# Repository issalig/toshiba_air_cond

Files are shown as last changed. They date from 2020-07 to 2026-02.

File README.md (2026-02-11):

# toshiba_air_cond
This project implements functions to decode Toshiba AB protocol from indoor units to wired controllers and provides a hardware design for communication.

Gerbers are available but remember if you improve the design please share it, that's how open source works, if you do not want to share, this project is not for you.

I strongly recommend to use [makusets' board](https://github.com/makusets/esphome-toshiba-ab/tree/main/hardware/D1%20mini) instead of my custom hardware.
My hardware is designed assuming a voltage level of the AB line around 15.6V when "1" and 14V when "0". Different voltage values will not work for writing while reading will work.

In particular, this project has been tested with remote control unit RBC-AMT32E and central unit RAV-SM406BTP-E (http://www.toshiba-aircon.co.uk/assets/uploads/product_assets/20131115_IM_1115460101_Standard_Duct_RAV-SM_6BTP-E_EN.pdf)

You can find the service manual from central unit and wired controller here: http://www.toshibaclim.com/Portals/0/Documentation/Manuels%20produits/SM_Gainable_Std-Compact--DI_406566806110614061606_GB.pdf, https://rednux.com/mediafiles/Hersteller/toshiba/Toshiba-Bedienungsanleitung-RBC-AMT32E-Englisch.pdf

## Index

[Software installation](#Software-installation)

[Web Interface](#Web-Interface)

[Home Assistant & MQTT](#Home-Assistant-&-MQTT)

[Hardware Installation](#Hardware-Installation)

[Custom hardware](#Custom-hardware)

[Data format](#Data-format)

[Message types](#Message-types)

[Other info](#Other-info)
 
# Software installation
[Up](#toshiba_air_cond) [Previous](#Index) [Next](#Hardware-Installation)

Code is developed in PlatformIO for ESP8266 and in particular for Wemos D1 mini board. It is basically a WebServer that serves a webpage and communicates with the client by means of WebSockets. It also offers Home Assistant integration and has nice features usch as OTA updates, file uploading, WifiManager and others.

### Dependencies

This project uses libraries and code from different authors, they are installed automatically from platformio.ini file

- [esp8266](https://github.com/esp8266/Arduino)
- [espsoftwareserial](https://github.com/plerup/espsoftwareserial) by Peter Lerup
- [WiFiManager](https://github.com/tzapu/WiFiManager) by tzapu
- [WebSockets](https://github.com/Links2004/arduinoWebSockets) by Links2004
- [ArduinoJson](https://github.com/bblanchon/ArduinoJson) by Benoit Blanchon
- [Adafruit libraries](https://github.com/adafruit) Adafruit SSD1306, Adafruit GFX Library, adafruit/Adafruit AHTX0 and adafruit/Adafruit BMP280
- LittleFS
- [PubSubClient](https://github.com/knolleary/pubsubclient)
- NTPClient

### Compilation
First things first. Compile it with VSCode and upload it to the board with PlatformIO.

Minimal hardware is ESP8266 and the pcb for adapting signal from serial to AB line. 

- ESP8266 (Wemos D1 Mini R2)
- Toshiba AC serial interface (SoftwareSerial D7=RX, D8=TX)
- Optional I2C sensors (shared bus D1=SCL, D2=SDA):
  - AHT20 (temperature + humidity)  [enabled with `#define USE_AHT20`]
  - BMP280 (temperature + pressure) [enabled with `#define USE_BMP280`]
  - BME280 (temperature + humidity + pressure) [enabled with `#define USE_BME280`]
- Optional OLED 128x64 SSD1306 (I2C D1=SCL, D2=SDA)         [`#define USE_SCREEN`]
- Reset / Config button on D4 (WiFiManager AP)
  
To sum up, the following defines are available and features are disabled by commenting its `#define` in  [config.h](https://github.com/issalig/toshiba_air_cond/blob/master/air/config.h)

- `USE_OTA`      OTA updates
- `USE_SCREEN`   OLED status display
- `USE_MQTT`     MQTT + Home Assistant integration
- `USE_AHT20`    AHT20 sensor support
- `USE_BMP280`   BMP280 sensor support

### WiFi setup
Once you have the code uploaded it is time to configure your WiFi. This project makes use of the great WiFiManager library so there is no need to hardcode your WiFi settings.
- Plug you esp board. It will start blinking.
- Connect to **airAP** wifi network from your cellphone or PC.
- Open a browser and the WifiManager will appear.
- Select your WiFi network and the password.
- If everything is correct, airAP shuts down and board connects to your WiFi.
- Connect to your normal WiFi from computer/cellphone.

### Connect
Now the esp8266 is connected to your network and can be reached as http://air.local

### Upload files
Connect to http://air.local/filemanager, type index.html and upload it.

This will store index.html file and http://air.local should show the main page.
You can use this endpoint to modify the webpage or add more functionality. If you do it please share.

### Delete files
Similarly to upload page you can use http://air.local/filemanager to delete a file.

### OTA and file update
OTA updates are available, so you do not need to unplug the esp everytime you want to flash it. In the Arduino IDE just set Tools->Port->air at xxx.
If you are using PlatformIO it is done in platform.io
Default OTA password is esp8266

```
; OTA upload configuration
upload_protocol = espota
upload_port = air.local        ; Replace with your device's actual IP from OTAName in config.cpp
upload_flags = --auth=esp8266  ; Replace with your OTA password from OTAPassword varialble in config.cpp
```

If you just want to upload individual files you can use http://air.local/edit.html

# Web Interface
[Up](#toshiba_air_cond) [Previous](#Software-Installation) [Next](#Hardware-Installation)

This section describes the features available through the embedded web interface served by the ESP8266 air conditioning controller.

## Access
- URL via mDNS: `http://air.local` (See `mdnsName` in `config.h`)
- HTTP Port: 80
- WebSocket Port: 81

web interface)

## Main Features
1. Control Functions
   - Power ON / OFF
   - Set target temperature (bounded 16–30 °C; internally enforced 18–30 in MQTT handler)
   - Change mode: `cool`, `heat`, `dry`, `fan_only`, `auto`, `off`
   - Change fan speed: `auto`, `low`, `medium`, `high`
   - Save mode

2. Timer
   - ON/OFF Timer. Software based relying only in esp8266

3. Chart
   - Shows current temperature, external temperature and pressure/humidity if sensors are available.

4. System
   - Info: IP, boot time and decoding errors.
   - Sensors: Internal / External AC sensors.
   - Address: Address configuration for master/remote in case your system uses different from default or you want to install different remotes.
   - Mode: 
    - Autonomous mode indicator: Use it if there is no remote connected (sends pings like remotes). It is necessary to have a temperature sensor to report room temperture.
    - Simulation mode indicator: Simulates a physical AC
   - Admin: Upload files. Use it to upload index.html and others.
5. Debug
    - Send RAW messages to AC, i.e., "00 FE 10 02 80 8A E6"
    - Debug output: Shows serial raw and decoded messages
    - Log

6. MQTT Configuration (if `USE_MQTT`)
   - Runtime modification of: host, port, username, password, device name
   - Persisted to `/mqtt_config.json` in LittleFS

# Home Assistant & MQTT
[Up](#toshiba_air_cond) [Previous](#Web-Interface) [Next](#Hardware-Installation)

If `USE_MQTT` is enabled, the device integrates with Home Assistant using MQTT Discovery.

### Discovery
The device automatically publishes configuration to:
`homeassistant/climate/toshiba_ac/config`

### Manual Configuration / Topics
If discovery is not used, here are the available topics:

| Topic Type | Topic Path | Payload / Description |
|---|---|---|
| **Status** | `homeassistant/ac/status/mode` | `cool`, `heat`, `auto`, `fan_only`, `dry`, `off` |
| **Status** | `homeassistant/ac/status/fan_mode` | `auto`, `high`, `medium`, `low` |
| **Status** | `homeassistant/ac/status/temperature` | Target Temperature (e.g. `22`) |
| **Status** | `homeassistant/ac/status/current_temperature` | Room Temperature (e.g. `21.5`) |
| **Command** | `homeassistant/ac/set/mode` | Set mode (same values as status + `on`/`off`) |
| **Command** | `homeassistant/ac/set/fan_mode` | Set fan speed |
| **Command** | `homeassistant/ac/set/temperature` | Set target temperature |

### Configuration
MQTT settings (Broker, User, Password) can be configured via the Web Interface and are saved to `/mqtt_config.json`. The device status (Power, Mode, Fan, Temperature) is periodically published and updated in real-time when changed via Web or Remote.

# Hardware installation
[Up](#toshiba_air_cond) [Previous](#Home-Assistant-&-MQTT) [Next](#Data-acquisition)

You will need an esp8266, a circuit for adapting signals to esp8266, a USB power supply, a a couple of dupont (female) wires.
- Take out the cover of your remote controller
- Loose the screws of AB terminals. **WARNING**: My PCB assumes A is positive and B is negative. If this is not your case you can damage the PCB. (https://github.com/issalig/toshiba_air_cond/discussions/40#discussioncomment-8149607)
- Pass the wires through the ventilation holes of the cover.
- Insert dupont wires on the terminals and screw them again
- Close the cover
- Connect dupont wires to the pcb (A,B)
- Plug the Wemos D1 mini into the pcb
- Power Wemos with usb cable and the led will start blinking (if you have already programmed it)

Just switch it on/off while you are in bed. If you like it just send me a beer and/or improve the project!

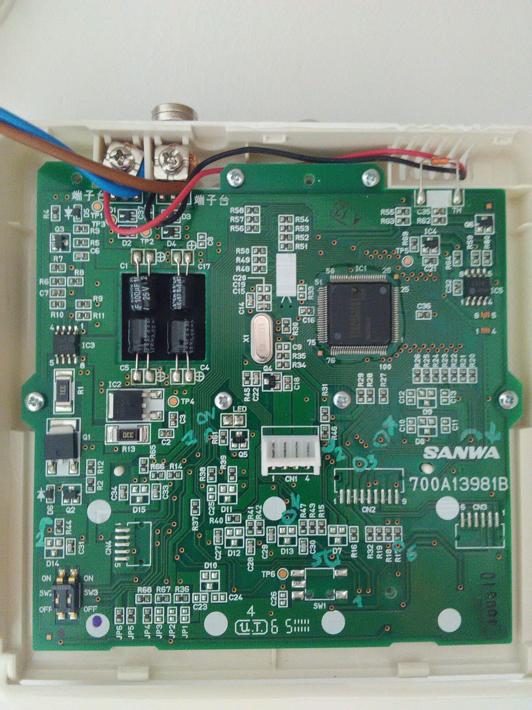
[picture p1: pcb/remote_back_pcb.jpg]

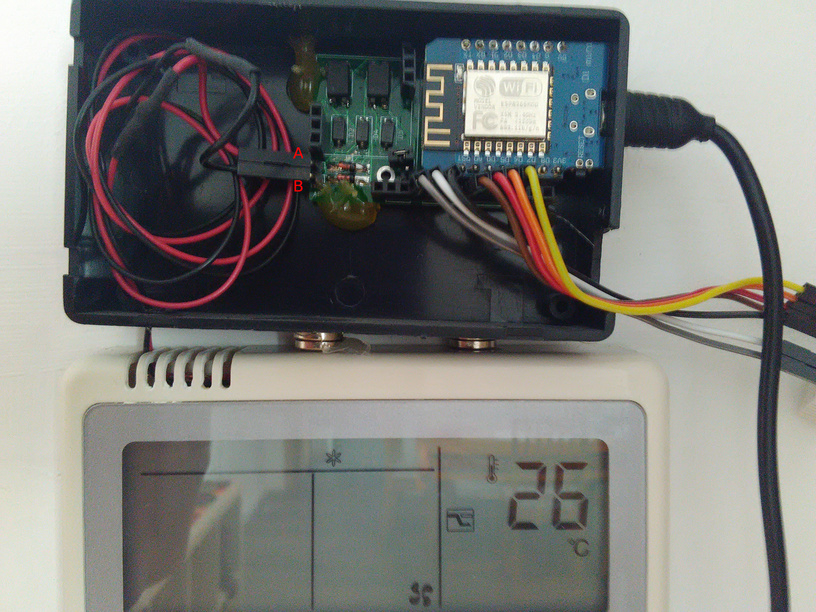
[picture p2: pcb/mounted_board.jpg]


# Data acquisition
[Up](#toshiba_air_cond) [Previous](#Hardware-Installation) [Next](#Custom-hardware)

This is how I managed to decode the information from the AB bus. First I plugged a multimeter to check the range of the signal and not fry anything. Then I used a DS0138 oscilloscope to monitor the signal and to guess voltages and baudrate (a resistor divider is suggested in order to lower the voltage). Later, an 8-channel USB logic analyzer (4-5 USD) can be used to capture data into the computer. **REMEMBER** to convert voltages to 0-3.3v before connecting it to logic analyzer or you will make magic smoke. You can use the read circuit below.

To capture data you can use pulseview with uart decoder 2400 bps, 8bits, start, stop, EVEN parity

In case you need it you can install the following packages
```
sudo apt install sigrok-cli
sudo apt install sigrok-firmware-fx2lafw
```

When the data has been validated visually you can use the following command line that reads RX data annotations and print one message per line according to 4th byte (message size).

```
sigrok-cli -P uart:rx=D0:baudrate=2400:parity_type=even -A uart=rx_data -i  YOURFILE  | awk '{pad =" "; b[len%4]=$2; if(len==3) {bytes="0x"b[len];  printf("%s%s%s%s%s%s%s%s",b[0],pad,b[1],pad,b[2],pad,b[3],pad)} if(len>3) {printf("%s%s",$2,pad);} len=len+1; if(len==4+bytes+1) {print "";len=0;bytes=0}}'
```

```
sigrok-cli -d fx2lafw -c samplerate=250000 -t D0=r -P uart:rx=D0:baudrate=2400:parity_type=even  -A uart=rx_data --continuous
```

# Custom hardware
[Up](#toshiba_air_cond) [Previous](#Data-acquisition) [Next](#Data-format)

Note: I strongly recommend to use [makusets board](https://github.com/makusets/esphome-toshiba-ab/tree/main/hardware/D1%20mini) instead of my custom hardware.
My hardware is designed assuming a voltage level of the AB line around 15.6V when "1" and 14V when "0". Different voltage values will not work for writing while reading will work.

I have designed some circuits to read and write the signal

## Read
I will use an optocoupler because it simplifies things and also isolates microcontroller from the rest of the system.

- Air conditioning side:
Voltage is around 15.6 volts when "1" and 14 when "0". A zener diode in reversed position provides 13V reference given that voltage is in the range [14, 15.6] and is > 13V. Thus, the signal is now in the range [1V, 2.6V]. Then, after diode 1N4001 (0.7V drop) voltage is 0.3V .. 1.9V, enough to activate the photodiode (1.2V) when "1" and to not activate it when "0".

IR led from optocouple drops 1.2v, and from signal we have a difference of 15.6V-13V=2.6V, thus 2.6V-1.2V=1.4V/100ohm = 14mA which has a maximum CTR=140%
Ic=3.3, If=14
CTR=Ic/If

```
Type     VZnom  IZT  for  rzjT    rzjk  at  IZK    IR  at  VR
1N4743A  13     19        <10     <100      0.25   <5      9.9
```

Now, let's calculate the resistor value
Izt=19 mA -> 2.6/19=130ohm  P=VI 2.6*19 =52mW

- Microcontroller side: 1k resistor limits the current. ESP8266 max current is 12mA > 3.3/1k = 3.3 mA

```
Air                                         Microcontroller
Conditioner

                          1N4001  _______
  A ---------+----100R ---->|----|       |-------3v3
             |                   | PC817 |
            10k                  |       |
             |                   |       |
  B --->|----+-------------------|_______|------ OUT               
                                             |
     zener 13v                              1k
      1N4743A                                |
                                            GND
             
```

## Write

Write circuit performs similarly to read circuit. 
- When OUT signal is "1", transistor and pullup resistor are "0", thus optocoupler is OFF and voltage is 15.6 (HIGH). 
- When OUT signal is 0, transistor is off and pullup resistor sends 1 and activates optocoupler and zener diode gives 13V (LOW).
Some systems recommend to set the Follower in the remote unit.

Here I attach the datasheets of the components.
https://www.onsemi.com/pub/Collateral/P2N2222A-D.PDF 
https://learnabout-electronics.org/Downloads/PC817%20optocoupler.pdf

```

              3v3                                    1N4001
               |                             |-----+---|<------- A               
              200                 _______    |     |               
               ------------------|       |---|     ^ zener 13v
               /                 | PC817 |         /
 OUT --1k- ---|   2N2222     |---|_______|---1k---| 2N2222
               \             |                     \
               |             |                     |
              GND           GND                    ------------- B

```

## Plan B. (In fact it was plan A but then I managed to decode AB protocol, yeah!)

To solder wires to button pads on the remote controller and close circuit to simulate pressing them (with and optocoupler).

``` 
                       _________
    uc OUT --- 200R----| PC817 |------- PAD+
                 GND---|_______|---4k7--PAD-
                                  
```

ESP8266 high level is 3v3 and the maximum current per pin is 12mA (but we will go safer with 10mA). Thus, the resistor for the IR diode of the optocoupler is 3.3-1.2/10=210 -> 200 ohm. 4k7 is a safe value since we just want continuity.

Following traces from button pads end in 2k resistors that we will use to solder wires. As R46 is common, we can think is button GND
ON button is connected to R25 and R46
Temp down button is connected to R23 adn R46
Temp up button is connected to R24 and R46

# Data format
[Up](#toshiba_air_cond) [Previous](#Custom-hardware) [Next](#Message-types)

Data packages have the following format:

|Source | Dest | Opcode 1  | Data Length | R/W mode | Opcode 2 | Payload | CRC |
|---|---|---|---|---|---|---|---|

Source/Dest (1 byte): 
|#|Description|
|---|---|
|00 | master (central unit) |
|40 | remote controller in the range [0x40..] |
|FE | broadcast |
|F0 | Group
|52 | ?? |

Data length (1 byte)
- Length of data field

R/W mode (1 byte)
|Mode|Desc|
|---|---|
|08 |for Write mode (from remote 40)|
|80 |for Read mode (from master 00)|

Payload can be empty such as in ping message 00 FE 10 02 80 8A E6.

CRC is computed as Checksum8 XOR of all the bytes (Compute it at https://www.scadacore.com/tools/programming-calculators/online-checksum-calculator/)

OpCode1 (byte 2)  indicates the function of the message and OpCode2 (byte 5) specifies the feature or register being targeted.

| OpCode1 | Description | Type | Example |
|---|---|---|---|
| `10` | Ping / Alive | `MSG_MASTER_ALIVE` | `00 FE 10 02 80 8A E6` |
| `11` | Write / Control | `MSG_POWER`, `MSG_SET_...` | `40 00 11 03 08 41 03 18` |
| `15` | Request / Query | `MSG_MODEL_REQUEST`... | `40 F0 15 02 00 08 AF` |
| `17` | Sensor Query | `MSG_SENSOR_QUERY` | `40 00 17 08 08 80 EF 00 2C 08 00 02 1E` |
| `18` | Response / Report | `MSG_MODEL_ANSWER`... | `00 40 18 14 80 08 52 41 56 2d 53 4d 31 31 30 36 42 54 50 2d 45 20 03 37 8e` |
| `1A` | Sensor Answer | `MSG_SENSOR_ANSWER` | `00 40 1A 07 80 EF 80 00 2C 00 2B B5` |
| `1C` | Status | `MSG_STATUS` | `00 FE 1C 0D 80 81 8D AC 00 00 76 00 33 33 01 00 01 B9` |
| `52` | Remote Start | - | - |
| `55` | Remote Temp | `MSG_REMOTE_SENSOR_TEMP` | `40 00 55 05 08 81 00 69 00 F0` |
| `58` | Ext. Status | `MSG_STATUS_EXT` | `00 FE 58 0F 80 81 34 A8 00 00 6C 6D E9 00 55 55 01 00 01 DC` |

| OpCode2 | Description | Type | Example |
|---|---|---|---|
| `02` | DN Codes | `MSG_DN_CODE` | `40 00 15 05 08 02 F5 00 01 AE` |
| `07` | Save Ratio | `MSG_SAVE_RATIO_...` | `00 40 18 03 80 07 4B 97` |
| `08` | Model Info | `MSG_MODEL_...` | `00 40 18 14 80 08 52 41 56 2d 53 4d 31 31 30 36 42 54 50 2d 45 20 03 37 8e` |
| `0A` | Temp Limits | `MSG_TEMP_LIMITS` | `00 40 18 10 80 0A 00 2F 0F 80 6A 80 6A 80 6A 80 6A 04 56 00 B0` |
| `0C` | Pong / Ping | `MSG_REMOTE_PING` | `40 00 15 07 08 0C 81 00 00 48 00 9F` |
| `0D` | Announce | `MSG_ANNOUNCE` | `40 F0 15 02 00 0D AA` |
| `0F` | Setpoints | `MSG_SETPOINT` | `00 40 18 09 80 0F 7A 74 78 78 25 52 05 A2` |
| `10` | Fan Caps | `MSG_FAN_MODES_...` | `00 40 18 0E 80 10 00 35 33 35 33 35 33 35 33 00 00 00 C6` |
| `27` | Errors | `MSG_SENSOR_ERROR` | `00 40 18 05 80 27 08 00 48 BA` |
| `41` | Power | `MSG_POWER` | `40 00 11 03 08 41 03 18` |
| `42` | Mode | `MSG_SET_MODE` | `40 00 11 03 08 42 01 19` |
| `4C` | Temp/Fan | `MSG_SET_TEMP_FAN` | `40 00 11 08 08 4C ...` |
| `54` | Save | `MSG_SAVE` | `40 00 11 04 08 54 01 01 09` |
| `80` | Sensor ID | `MSG_SENSOR_QUERY` | `40 00 17 08 08 80 EF 00 2C 08 00 02 1E` |
| `81` | Status | `MSG_STATUS` | `00 FE 1C 0D 80 81 8D AC 00 00 76 00 33 33 01 00 01 B9` |
| `86` | Mode Stat | `MSG_STATUS_MODE` | `00 52 11 04 80 86 84 01 C4` |
| `8A` | Alive | `MSG_MASTER_ALIVE` | `00 FE 10 02 80 8A E6` |
| `A1` | ACK | `MSG_MASTER_ACK` | `00 40 18 02 80 A1 7B` |
| `A3` | Busy | `MSG_MASTER_BUSY` | `00 40 18 02 80 A3 79` |
| `E8` | Time | `MSG_TIME_COUNTER` | `40 00 15 06 08 E8 00 01 00 9E 2C` |
| `EF` | Sensor Val | `MSG_SENSOR_ANSWER` | `00 40 1A 07 80 EF 80 00 2C 00 2B B5` |

# Message types

[Up](#toshiba_air_cond) [Previous](#Data-format) [Next](#Other-info)

The protocol relies on a command/response structure. Most control commands are sent by the Remote (0x40), and the Master (0x00) responds with status updates or acknowledgments.

Temperatures are coded with the formula: `(Value >> 1) - 35`. That is, for a value of `0x78`, the temperature is `(0x78 >> 1) - 35 = 120/2 - 35 = 60 - 35 = 25°C`.

## 1. Control Commands (Remote -> Master)
These commands control the state of the AC unit.

| Command | OpCode 1 | OpCode 2 | Type | Data Structure (Example) | Description |
|---|---|---|---|---|---|
| **Power** | `11` | `41` | `MSG_POWER` | `40 00 11 03 08 41 [Value] [CRC]`  | `Value`: `03`=ON, `02`=OFF |
| **Mode**  | `11` | `42` | `MSG_SET_MODE` | `40 00 11 03 08 42 [Mode] [CRC]` | `Mode`: `01`=Heat, `02`=Cool, `03`=Fan, `04`=Dry, `05`=Auto |
| **Temp/Fan**| `11` | `4C` | `MSG_SET_TEMP_FAN` | `40 00 11 08 08 4C [Mode+] [Fan+]...` | Combined Setpoint (Temp, Fan, Mode) |
| **Save** | `11` | `54` | `MSG_SAVE` | `40 00 11 04 08 54 01 [Value] [CRC]` | `Value`: `01`=ON, `00`=OFF |
| **Ping** | `15` | `0C 81` | `MSG_REMOTE_PING` | `40 00 15 07 08 0C 81 00 00 48 00 9F` | Keep-alive / check presence |
| **Timer** | `11` | `0C 82` | - | `40 00 11 09 08 0C 82 00 00 30 05 01 01 EB` | Timer settings |
| **Req. DN** | `15` | `02` | `MSG_DN_CODE_REQUEST` | `40 00 15 05 08 02 F5 00 01 AE` | Request DN Code value. `Code` in byte 6 |
| **Save Ratio** | `15` | `07` | `MSG_SAVE_RATIO_REQUEST` | `40 00 15 04 08 07 00 C2 9C` | Request power save ratio |
| **Model** | `15` | `08` | `MSG_MODEL_REQUEST` | `40 00 15 02 08 08 AF` | Request model information |
| **Limits** | `15` | `0A` | `MSG_TEMP_LIMITS_REQUEST` | `40 00 15 02 08 0A 55` | Request temp limits |
| **Features** | `15` | `0D` | `MSG_ANNOUNCE` | `40 F0 15 02 00 0D AA` | Announce / Request features |
| **Setpoints** | `15` | `0F` | `MSG_SETPOINT_REQUEST` | `40 00 15 02 08 0F 50` | Request setpoints |
| **Fan Caps** | `15` | `10` | `MSG_FAN_MODES_REQUEST` | `40 00 15 02 08 10 4F` | Request fan capabilities |
| **Time Cnt** | `15` | `E8` | `MSG_TIME_COUNTER` | `40 00 15 06 08 E8 00 01 00 9E 2C` | Request time counter (?) |
| **Sensor Query**| `17` | `80` | `MSG_SENSOR_QUERY` | `40 00 17 08 08 80 EF 00 2C 08 00 02 1E` | Request specific sensor value |
| **Remote Temp** | `55` | `81` | `MSG_REMOTE_SENSOR_TEMP` | `40 00 55 05 08 81 00 [Val] 00 [CRC]` | Temperature in byte 7|

**Temperature and Fan Speed (OpCode 4C) Breakdown:**
The `4C` packet is used when changing Temperature or Fan Speed. It contains multiple state variables.
`40 00 11 08 08 4C [Byte6] [Byte7] [Byte8] 00 [ModeCheck] [ModeCheck] [CRC]`
*   **Byte 6 (Mode)**: `0x10` + Mode (`02`=Cool, `01`=Heat, etc.)
*   **Byte 7 (Fan)**: `0x18` + Fan (`0`=Auto, `1`=High, `2`=Med, `5`=Low) -> *Note: bitmasks vary*
*   **Byte 8 (Temp)**: `((TargetTemp + 35) << 1)`
*   **ModeCheck**: `0x33` for Cool/Dry/Fan/Auto, `0x55` for Heat.

## 2. Status Reports & Answers (Master -> Remote)
The Master unit periodically broadcasts its status or responds to specific queries.

| Message | OpCode 1 | OpCode 2 | Type | Data Structure (Example) | Description |
|---|---|---|---|---|---|
| **Status** | `1C` | `81` | `MSG_STATUS` | `00 FE 1C 0D 80 81 8D AC 00 00 76 00 33 33 01 00 01 B9` | Standard periodic status (Power, Mode, Fan, RoomTemp) |
| **Ext. Status**| `58` | `81` | `MSG_STATUS_EXT` | `00 FE 58 0F 80 81 34 A8 00 00 6C 6D E9 00 55 55 01 00 01 DC` | Extended status (Filter, Preheat, Errors, Extra Temps) |
| **Alive** | `10` | `8A` | `MSG_MASTER_ALIVE` | `00 FE 10 02 80 8A E6` | Frequent Keep-Alive broadcast from Master |
| **ACK** | `18` | `A1` | `MSG_MASTER_ACK` | `00 40 18 02 80 A1 7B` | Acknowledgment after a valid setting change |
| **Busy** | `18` | `A3` | `MSG_MASTER_BUSY` | `00 40 18 02 80 A3 79` | Master is busy processing command |
| **Pong** | `18` | `0C` | `MSG_MASTER_PONG` | `00 40 18 08 80 0C 00 03 00 00 48 00 97` | Response to Remote Ping |
| **Mode Stat**| `11` | `86` | `MSG_STATUS_MODE` | `00 52 11 04 80 86 84 01 C4` | Mode confirmation |
| **DN Code** | `18` | `02` | `MSG_DN_CODE` | `00 40 18 07 80 02 01 02 05 00 00 DB` | Response with DN Code value |
| **Save Ratio**| `18` | `07` | `MSG_SAVE_RATIO_ANSWER` | `00 40 18 03 80 07 4B 97` | Response with power save ratio |
| **Model** | `18` | `08` | `MSG_MODEL_ANSWER` | `00 40 18 14 80 08 52 41 56 2d 53 4d 31 31 30 36 42 54 50 2d 45 20 03 37 8e` | Response with model string |
| **Limits** | `18` | `0A` | `MSG_TEMP_LIMITS` | `00 40 18 10 80 0A 00 2F 0F 80 6A 80 6A 80 6A 80 6A 04 56 00 B0` | Response with temp limits |
| **Features** | `18` | `0D` | `MSG_FEATURES` | `00 40 18 12 80 0D 08 00 FE FE FE FE FE FE FE FE FE FE FE FE FE FE CD` | Response with supported features |
| **Setpoints** | `18` | `0F` | `MSG_SETPOINT` | `00 40 18 09 80 0F 7A 74 78 78 25 52 05 A2` | Response with setpoints |
| **Fan Caps** | `18` | `10` | `MSG_FAN_MODES_ANSWER` | `00 40 18 0E 80 10 00 35 33 35 33 35 33 35 33 00 00 00 C6` | Response with fan capabilities |
| **Errors** | `18` | `27` | `MSG_SENSOR_ERROR` | `00 40 18 05 80 27 08 00 48 BA` | Error history report |
| **Time Cnt** | `18` | `E8` | `MSG_TIME_COUNTER_ANSWER` | `00 40 18 07 80 E8 00 01 00 01 83 B4` | Response with time counter |
| **Sensor** | `1A` | `EF` | `MSG_SENSOR_ANSWER` | `00 40 1A 07 80 EF 80 00 2C 00 2B B5` | Response with sensor value |

**Status Packet (OpCode 1C):**
`00 FE 1C 0D 80 81 [D1] [D2] 00 00 [Temp] 00 [Chk] [Chk] [Sv] 00 [Pwr] [CRC]`
*   **D1 (Mode)**: Mode is in bits 7-5. `0x80` mask often seen.
*   **D2 (Fan)**: Fan speed in bits 7-5.
*   **Temp**: `((Value >> 1) - 35)` = Room Temperature.
*   **Sv (Save)**: Bit 0 indicates Save Mode.
*   **Pwr**: Bit 0 indicates Power (1=ON).

## 3. Remote Announce Protocol

### 1. Announce / Discovery (Remote -> System)
In the master bootup process (you need to switch off and on the master), the remote controller sends an **Announce** message to the broadcast address (`0xF0`).
*   **Message**: `40 F0 15 02 00 0D AA`
    *   **Source**: `0x40` (Remote)
    *   **Dest**: `0xF0` (Discovery / Broadcast)
    *   **OpCode**: `15` (Request) ... `0D` (Announce)

If the master is busy it will respond with `MSG_MASTER_BUSY`
*   **Message**: `00 40 18 02 80 A3 79`
    *   **Source**: `0x00` (Master)
    *   **Dest**: `0x40` (Remote)
    *   **OpCode**: `18` (Response) ... `A3` (Busy) 

otherwise it will respond with `MSG_FEATURES` and that means the remote is linked. **Take into account that for the remote to work it needs to be linked to the master.** This is not necessary if you already have a remote linked to the master (i.e. your RBC-AMT32E).
*   **Message**: `00 40 18 12 80 0d 08 00 fe fe fe fe fe fe fe fe fe fe fe fe fe fe cf`
    *   **Source**: `0x00` (Master)
    *   **Dest**: `0x40` (Remote)
    *   **OpCode**: `18` (Response) ... `0D` (Features)
    *   **Payload**: `0x12` (18 bytes)
    *   **Data**: The sequence `FE FE...` likely represents a bitmap of supported features (modes, fan speeds, louvers, etc.) enabled on the indoor unit.

After the reception of `MSG_FEATURES` the remote will ask for the following information:
* Model info
* Temperature Limits
* Capabilities
* Power Save Ratio
* Current Setpoint

**Model**:
*   Request: `40 F0 15 02 00 08 AF`
*   Response: `00 00 18 0D 00 08 [Model String] [CRC]` (e.g. `RAV-SM406...`)

**Temperature Limits**:
*   Request: `40 00 15 02 08 0A 55`
*   Response: `00 40 18 10 80 0A 00 2F 0F 80 6A 80 6A 80 6A 80 6A 04 56 00 B0` (Example)
    *   Byte 9: Max Temp (`0x80` -> 29°C)
    *   Byte 10: Min Temp (`0x6A` -> 18°C)
    *   Byte 17: Frost Protection Flag (`0x04` = Enabled)
    *   Byte 18: Frost Protection Temp (`0x56` -> 8°C)
    *   Formula: `(Value >> 1) - 35`

**Power Save Ratio**:
*   Request: `40 00 15 04 08 07 00 C2 9C`
*   Response: `00 40 18 03 80 07 4B 97` (Value: 0x4B = 75%)

**Current Setpoint**:
*   Request: `40 00 15 02 08 0F 50`
*   Response: `00 40 18 09 80 0F 7A 74 78 78 25 52 05 A2` (Example)
    *   Bytes 6-9: Default temperatures for Auto, Heat, Dry, Cool.
    *   Formula: `(Value >> 1) - 35`
    *   Example Values:
        *   Auto: `0x7A` -> 26°C
        *   Heat: `0x74` -> 23°C
        *   Dry:  `0x78` -> 25°C
        *   Cool: `0x78` -> 25°C

**Capabilities**: This message is still UNDER STUDY, so it is not yet clear what the values mean.
*   Request: `40 00 15 02 08 10 50`
*   Response: `00 40 18 0E 80 10 00 35 33 35 33 35 33 35 33 00 00 00 C6` (Example)
    *   Bytes 6-9: ??.

**Time Sync / Counter**:
*   Message: `40 00 15 06 08 E8 00 01 00 9E 2C` (Sent every minute by Remote in some units)

## 4. Sensor & Maintenance

**Query Sensor**: Request specific sensor ID (see Sensor Addresses)
*   Request: `40 00 17 08 08 80 ef 00 2c 08 00 [SENSOR] [CRC]`
    * Opcode 17 80
    * Byte 11: Sensor ID
*   Response: `00 40 1A 07 80 EF 80 00 2C [ValH] [ValL] [CRC]`
    * Opcode 1A EF
    * Byte 9: High Byte
    * Byte 10: Low Byte
    * Value: `(Byte9 << 8) | Byte10`
    * If `Value == 0xA2`, the value is undefined.

# Sensor addresses

| No.  | Desc  |
|---|---|---|
| 00 | Room Temp (Control Temp) (°C) |
| 01 | Room temperature (remote controller) |
| 02 | Indoor unit intake air temperature (TA) |
| 03 | Indoor unit heat exchanger (coil) temperature (TCJ) Liquid |
| 04 | Indoor unit heat exchanger (coil) temperature (TC) Vapor |
| 07 | Indoor Fan Speed|  |
| 60 | Outdoor unit heat exchanger (coil) temperature (TE) |
| 61 | Outside air temperature (TO)| |
| 62 | Compressor discharge temperature (TD) |
| 63 | Compressor suction temperature (TS) |
| 65 | Heatsink temperature (THS) |
| 6a | Operating current (x1/10) |
| 6d | TL Liquid Temp (°C) |
| 70 | Compressor Frequency (rps)| |
| 72 | Fan Speed (Lower) (rpm) |
| 73 | Fan Speed (Upper) (rpm) |
| f1 | Compressor cumulative operating hours (x100 h) |
| f2 | Fan Run Time (x 100h) |
| f3 | Filter sign time x 1h | 
| f8 | Indoor Discharge Temperature |

## 5. DN Codes
DN Codes are configuration settings for the Toshiba AC unit. Here only read functionality is described.

### Request
The specific DN code is requested using OpCode `15 02`.

`40 00 15 05 08 02 [Mode] [Code] [Offset] [CRC]`

*   **Mode**: Defines the traversal method.
    *   `0xF5`: Request **Current** specific code.
    *   `0xF1`: Request **Next** available code.
    *   `0xF2`: Request **Previous** available code.
*   **Code**: DN Code address
*   **Offset**: Typically `0x00` for current, `0x01` for next/prev.

### Response
The Master returns the value for the DN code.

`00 40 18 07 80 02 [RefCode] [Value] [Unk1] [Unk2] [Unk3] [CRC]`

*   **RefCode** (Byte 6): Often points to the *next* code or context.
*   **Value** (Byte 7): The value of the requested DN Code.
*   **Unk1-3**: Unknown data (possibly related to min/max or permissions).

**Example**:
*   Request: `40 00 15 05 08 02 f5 01 00 ae` (Request Code 01)
    *   Response: `00 40 18 07 80 02 01 02 05 00 00 db`
    *   Here, Byte 7 (`0x02`) is the value. Byte 6 (`0x01`) is current code given F5 "current" mode was used.

### DN Codes List
These codes define various configuration parameters.

| Code | Description |
|---|---|
| `01` | Filter alarm time |
| `02` | Dirty state |
| `03` | Central ctl address |
| `04` | Specific indoor priority |
| `05` | Fan control heating |
| `06` | Heating temp shift |
| `0C` | Preparing indication |
| `0D` | Auto mode existence |
| `0E` | FS Box |
| `0F` | Heat mode |
| `10` | Type |
| `11` | Indoor unit capacity |
| `12` | System address |
| `13` | Indoor unit address |
| `14` | Group master/slave |
| `16` | Indoor fan speed |
| `1E` | Dead band |
| `1F` | Max set temp cool |
| `20` | Min set temp cool |
| `21` | Max set temp heat |
| `22` | Min set temp heat |
| `23` | Max set temp dry |
| `24` | Min set temp dry |
| `25` | Max set temp auto |
| `26` | Min set temp auto |
| `28` | Auto restart |
| `2A` | CN70 |
| `2E` | CN61 |
| `31` | External fan control |
| `32` | TA sensor (0 Body, 1 Remote) |
| `33` | Temperature unit (0 C, 1 F) |
| `45` | Anti-smudge louver |
| `49` | 24h ventilation |
| `4C` | Night purge |
| `5D` | Standard ducted |
| `60` | Timer set |
| `62` | Anti-smudge fan speed |
| `69` | Louver position |
| `77` | Dust set point |
| `86` | Correction strong heating |
| `88` | Air direction setting |
| `9A` | Fan control cooling |
| `9B` | Hot start |
| `D0` | Power saving |
| `F0` | Swing mode |
| `F1` | Louver 1 |
| `F2` | Louver 2 |
| `F3` | Louver 3 |
| `F4` | Louver 4 |
| `F6` | Application ctl kit |
| `FE` | Group control |

# TO-DOS
[Up](#toshiba_air_cond) [Previous](#Message-types) [Next](#Other-info)

- Improve PCB

- Fix PCB: jumper for Hardware or Software Serial

- Fix parsing to support round buffer and not to loose partial frames (not necessary)

- Clearer Protocol documentation

- Check other circuits as:80
  - https://easyeda.com/marcegli/door-opener
  - https://frog32.ch/smart-intercom.html 
  - https://electronics.stackexchange.com/questions/458996/logic-level-converter-for-nodemcu-esp8266-input-24v-16v-hi-lo-500-baud 
  - https://sudonull.com/post/18480-We-pump-the-intercom-with-the-MQTT-protocol-to-control-from-the-phone
  - https://hackaday.com/2019/01/07/building-an-esp8266-doorbell-on-hard-mode/
  - https://daeconsulting.co.za/2018/12/17/theres-someone-at-the-door/

- Announce project in other similar ones
  - https://github.com/ToniA/arduino-heatpumpir/
  - https://github.com/openenergymonitor
  - https://github.com/roarfred/AmsToMqttBridge
  - https://github.com/dgoodlad/esp8266-mitsubishi-aircon
  - https://github.com/H4jen/webasto_sniffer

# Other info
[Up](#toshiba_air_cond) [Previous](#Message-types)

If you want to know about error codes and sensor addresses you can check the following links.
http://www.toshiba-aircon.co.uk/assets/uploads/pdf/sales_tools/Technical_Handbook_ver._13.1.pdf
https://www.cdlweb.info/wp-content/uploads/2020/10/1-CDL-Toshiba-R32-Technical-Handbook-V10-2020.pdf
https://www.toshibaclim.com/Portals/0/Documentation/Manuels%20produits/SM_CassetteUTP_DI-SDI-111416-E_GB.pdf

I found this projects interesting even that it is not the same protocol https://github.com/H4jen/webasto_sniffer
https://echonet.jp/wp/wp-content/uploads/pdf/General/Standard/Release/Release_F_en/SpecAppendixF_e.pdf

Info about commercial gateways but no info about protocol :(

Connections https://www.toshibaclim.com/Portals/0/Documentation/Manuels%20produits/SM_CassetteUTP_DI-SDI-111416-E_GB.pdf
Sensor addresses (pg 52) http://www.toshiba-aircon.co.uk/assets/uploads/pdf/sales_tools/New_Technical_Handbook_version_14_1_3.pdf
Sensor addresses (pg 73) https://www.toshibaclim.com/Portals/0/Documentation/Manuels%20produits/SM_CassetteUTP_DI-SDI-111416-E_GB.pdf
Sensor addresses (pg 42) http://www.toshiba-aircon.co.uk/assets/uploads/pdf/sales_tools/Technical_Handbook_ver._13.1.pdf

Error codes from Toshiba (pg 38) https://cdn.shopify.com/s/files/1/1144/2302/files/BP-STD_Toshiba_v1_08.pdf
Temperature formula TCS-Net https://www.toshibaheatpumps.com/application/files/8914/8124/4818/Owners_Manual_-_Modbus_TCB-IFMB640TLE_E88909601.pdf
https://www.toshibaheatpumps.com/customer-support/owner-manuals
https://www.intesisbox.com/intesis/product/media/intesisbox_to-ac-knx-16-64_user_manual_en.pdf?v=2.2

The unit where I have tested the project is model RAV-SM406BTP-E  which stands for

```
RAV-SM406BTP-E 
|     | |    |- CE marking
|     | ||-Duct
|     | |-gen
|     |-duty 4.0 kW 
|   |-Digital inverter
|- Light comercial
```

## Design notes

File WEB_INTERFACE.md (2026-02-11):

# Web Interface

This document describes the features available through the embedded web interface served by the ESP8266 air conditioning controller.

## Access
- URL via mDNS: `http://air.local` (See `mdnsName` in `config.h`)
- HTTP Port: 80
- WebSocket Port: 81

| Main screen

## Main Features
1. Control Functions
   - Power ON / OFF
   - Set target temperature (bounded 16–30 °C; internally enforced 18–30 in MQTT handler)
   - Change mode: `cool`, `heat`, `dry`, `fan_only`, `auto`, `off`
   - Change fan speed: `auto`, `low`, `medium`, `high`
   - Save mode

2. Timer
   - ON/OFF Timer. Software based relying only in esp8266

3. Chart
   - Shows current temperature, external temperature and pressure/humidity if sensors are available.

4. System
   - Info: 
     - IP, boot time, memory usage.
     - **Serial Statistics**: Detailed breakdown of decoded messages, discarded bytes/messages, and *recovered messages* (packets fixed by CRC repair).
     - **Announce State**: Current link status with the AC unit (UNLINKED, BUSY, LINKED).
   - Sensors: Internal / External AC sensors.
   - Address: 
     - **Sync**: Automatically detect and adopt addresses from observed traffic.
     - **Manual Set**: Configure specific Master/Remote addresses.
     - **Reset**: Restore default addresses (Master: 0x00, Remote: 0x40).
   - Modes: 
     - **Autonomous Mode**: Control loop to act as a remote (every 8s). Can be Start/Stopped.
     - **Simulation Mode**: Simulates a physical AC for testing UI/Integrations without hardware.
     - **Listen Mode**: Prioritizes serial RX (passive monitoring).
   - Settings:
     - **Persist**: Save/Load current configuration (Pins, etc.) to LittleFS.
     - **Hardware Config**: Runtime configuration of Serial (RX/TX/Buf) and I2C pins.
   - Admin: Upload files. Use it to upload `index.html` and others.
5. Debug
    - **Send RAW**: Send hex strings directly to the AC, i.e., "00 FE 10 02 80 8A E6".
    - **Explore Sensors**: Query arbitrary sensor IDs (0x00-0xFF) to discover undocumented values.
    - **Explore DN Codes**: Query configuration (DN) codes from the AC unit.
    - **Traffic Monitor**: Real-time view of `last_cmd` (sent) and `rx_data` (received), including recovered packets marker `<REC>`.
    - Log: System event log.

6. MQTT Configuration (if `USE_MQTT`)
   - **Runtime Config**: Modify host, port, user, password, device name without recompiling.
   - **Status**: View current connection status and test connection.
   - **Discovery**: Send/Reset Home Assistant discovery messages.
   - Persisted to `/mqtt_config.json` in LittleFS.

## Techincal details

1. File Management / Content Update
   - `upload.html` page (served directly from program memory via `upload_html.h`) allows file upload to LittleFS when there are no files.
   - Success redirect to `success.html`

2. Data & Persistence
   - Current status periodically serialized to `/status.json`
   - Hardware & Runtime settings persisted to `/settings.json`
   - Historical circular buffers in RAM for temperatures, humidity, pressure, timestamps (not persisted by default)
   - Remote access to raw files if exact path is known (no directory listing provided)

3. WebSocket Live Updates
   - Bi‑directional JSON messaging (see `processRequest()` logic)
   - Push notifications on state changes (e.g. after MQTT command processed, `notifyWebSocketClients()`)
   - Real‑time reflection of simulation adjustments and sensor readings

4. OTA & Maintenance (if `USE_OTA`)
   - Firmware updated via Arduino OTA (password in `config.h`)
   - Web assets updated through file upload (no firmware flashing required for UI tweaks)

## Message & Command Flow
| Action | Transport | Handler |
|---|---|---|
| UI control (temp/mode/fan/power) | WebSocket JSON | `processRequest()` → AC protocol / simulation
| Periodic sensor & status updates | Timers → WebSocket | `handleStatus()`, `handleTemperature()`
| MQTT incoming setpoints | MQTT subscribe topics | `mqttCallback()` → AC / simulation + WebSocket notify
| File upload | HTTP POST `/edit.html` or `/upload.html` | `handleFileUpload()`

## MQTT Topics (Summary)
Published (state):
- `homeassistant/ac/status/mode`
- `homeassistant/ac/status/fan_mode`
- `homeassistant/ac/status/temperature` (target)
- `homeassistant/ac/status/current_temperature`

Subscribed (commands):
- `homeassistant/ac/set/mode`
- `homeassistant/ac/set/fan_mode`
- `homeassistant/ac/set/temperature`

Home Assistant discovery config retained at:
- `homeassistant/climate/toshiba_ac/config`

## File System Notes
- Compression: Prefer uploading `.gz` versions of large assets (served automatically)
- Config files:
  - `/mqtt_config.json`
  - `/settings.json` (hardware & runtime config)
  - `/status.json` (periodic snapshot)
- Space is limited; remove unused large assets before OTA updates

## Security Considerations
- No HTTP authentication by default (add if exposing beyond LAN)
- OTA protected by password (see `config.h`)
- MQTT credentials stored in plaintext in LittleFS; restrict physical and network access

## Extending the UI
1. Add or modify HTML/JS/CSS in `data/` and upload (or create gzipped versions)
2. Add new WebSocket commands: implement in `processRequest.cpp` and update front‑end JS

## Build‑Time Feature Flags
| Flag | Effect |
|---|---|
| `USE_MQTT` | Enables MQTT client, discovery & topics |
| `USE_SCREEN` | Enables OLED display updates |
| `USE_AHT20` / `USE_BMP280` | Enable corresponding sensors |
| `USE_OTA` | Activates OTA service |

## Quick Troubleshooting
| Symptom | Check |
|---|---|
| No web page | WiFi connection, mDNS name, LittleFS upload success |
| Stale data | WebSocket connection, browser console, `webSocket.loop()` activity |
| MQTT offline | Broker reachability, `/mqtt_config.json`, WiFi status |
| Commands ignored (simulation) | Ensure `simulation_mode` state matches expectations |
| OTA fails | Correct password, same network, firewall rules |

---
This file documents only the web interface & related runtime services. See the main `README.md` for full architectural details.

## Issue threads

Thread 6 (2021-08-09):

Unexpected resets

issalig, 2021-08-09:
Sometimes, ESP8266 resets.
It can stay for some days wo resetting or just every few minutes.
I guess it is something related to ArduinoJSON but not sure. It does not appear to be a memory leak.
Other theory is that there are power problems but it is connected to a 5V 2A, so it should be like this.

issalig, 2021-11-02:
For some unknown reason, after 50 days without resetting I close this issue.

issalig, 2022-01-04:
After a lot of analysis I may have solved the problem. After some minutes without connecting when a new connection entered SPIFFS tried to get the page but it took a lot and esp_yield crash.

I have replecaed SPIFFS for LittleFS and now it works ok.
Hope it is definitely the solution

issalig, 2022-01-29:
LittleFS also hangs but it looks like gzipping the files can be a solution https://github.com/me-no-dev/ESPAsyncWebServer/issues/825

Also it is worth to mention that max opened files is 5

issalig, 2022-02-06:
It seems that SPIFFS was not the problem, it was a silly error and I commented websocket.loop by error some months ago.

Thanks to @cmc88 for finding the bug.

issalig, 2022-07-28:
I am still getting unexpected crashes.
For now I will force a reset every 1/2 hours to clean everything

Closed 2022-02-06.

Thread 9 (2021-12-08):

Suggestions for next pcb version

issalig, 2021-12-08:
Add buttons on pcb for
- Enter into wifi manager
- Reset

Add OLED screen.

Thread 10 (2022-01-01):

[Help] Decoding with sigrok

uploader18, 2022-01-01:
I am working in decoding Toshiba indoor to outdoor communication protocol and need help.I have a wave form taken with sigrok and can't decode it.

If you are so kind write me an email so i have yours.

My mail: uploader18@gmail.com

Regards Ziga

issalig, 2022-01-01:
Hi, for technical stuff I prefer to communicate through github, that way others can learn and contribute.

Some things you should take into account when using sigrok and saelae logic analizer
- sampling rate, according to Nyquist theorem it should be at least 2x than the frequency you want to capture.
- be sure signal is in the range 0 - 3.3V (not sure if it is 5V, so I stay safe at 3.3v)

Not sure if you still tried but in order to decode (serial protocol) , you should go for the decoder (waveform icon in pulseview) and select UART. And then try all the different combinations :)

Can you share the waveform? wetransfer, pastebin, etc, ...

BR

uploader18, 2022-01-01:
Hi, I agree with you that we should share it over github but till now i
only know it is ModBusRTU protocol, 300 baudrate and that is it.I am
attaching sigrok file and page from service manual on what data is sent to
outdoor unit.For now i only have data from cooling mode.

<https://www.avast.com/sig-email?utm_medium=email&utm_source=link&utm_campaign=sig-email&utm_content=webmail>
Virus-free.
www.avast.com
<https://www.avast.com/sig-email?utm_medium=email&utm_source=link&utm_campaign=sig-email&utm_content=webmail>
<#DAB4FAD8-2DD7-40BB-A1B8-4E2AA1F9FDF2>

V V sob., 1. jan. 2022 ob 21:14 je oseba issalig ***@***.***>
napisala:

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

uploader18, 2022-01-01:
Hi, I agree with you that we should share it over github but till now i only know it is ModBusRTU protocol, 300 baudrate and that is it.I am attaching sigrok file and page from service manual on what data is sent to outdoor unit.For now i only have data from cooling mode.

[cooling 17c vent3.zip](https://github.com/issalig/toshiba_air_cond/files/7798231/cooling.17c.vent3.zip)
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

issalig, 2022-01-01:
Looks like .sal format is not supported by sigrok (at least my installation, maybe recompiling with saleae format support could be possible, but haven't tried)

Can you provide a CSV file or other format?

uploader18, 2022-01-01:
I used Logic 2 to capture it.

https://support.saleae.com/logic-software/sw-download

Regards, Ziga

issalig, 2022-01-01:
Ok, I loaded it into Logic2 and what I see looks that there are problems with signal, small pulses that can be noise, a poor voltage level, maybe less than 2V (see https://en.wikipedia.org/wiki/Logic_level)

I also see that in RX this small pulses are 167 ns wide that would be 6Mhz approx 6000000 baudrate that it is not what is expected, I guess it will be more in the range of 2400 (typical values are 110, 300, 600, 1200, 2400, 4800, 9600, 14400, 19200, 38400, 57600, 115200, 128000 and 256000 )

Try to set this filter  https://support.saleae.com/user-guide/using-logic/software-glitch-filter and capture the signal again.

If you have and oscilloscope try to visualize the signal, the smallest pulse (given there are no glitches) will tell you the baudrate

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

issalig, 2022-01-02:
I played this morning a little bit, for RX signal the shortest pulse shows that it could be a 100 bps signal (also a 150bps), then playing with standard 8N1 produces a result without framing errors that does not mean it is the right one but a candidate.
But it is strange that "0" pulses are about 7.5 ms while "1" are 11.93 ms,
I guessed the baudrate manually but here they give some hints and there is even an extension https://support.saleae.com/protocol-analyzers/analyzer-user-guides/using-async-serial

For TX there are a lot of errors, probably caused by the glitches that confuse the decoder.
It is also worth to notice that there are 1.66 ms "0" pulses that do not seem to be just noise, but this pulse width would mean much higher baudrate while RX line seems to be around 100.

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

I attach you the .sal file with the decoding
[cooling_17c_vent3_serial.zip](https://github.com/issalig/toshiba_air_cond/files/7798945/cooling_17c_vent3_serial.zip)

uploader18, 2022-01-02:
I captured it again with 1us filter

[cooling mode with 1us filter.zip](https://github.com/issalig/toshiba_air_cond/files/7799419/cooling.mode.with.1us.filter.zip)

issalig, 2022-01-02:
It looks better glitches are over, but this small pulses in the TX line confuse me (see image). Also RX line look like a CLK signal

How do you get pulsview output? Just using pulseview or converting it from .sal ?

I have been able to decode without errors using serial protocol with 120 baudrate 8N1  and RX non-inverted and TX inverted but I do not think thos e are the right parameters, they just fit.
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

Do you have experience with modbus? Do you think is it a modbus signal?

uploader18, 2022-01-02:
There is no RX or TX line it is single wire and ground it communicates over power cables. I am adding a picture from service manual so you can see how it is connected.

I used pulsewiev.

With serial protocol it is too easy or is it, if it is then we must check, i will make a signal capture with cooling and one with heating and we will see what if anything changes and to be sure I will capture first for cooling twice in a row and heating twice so that we see if anything changes.

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

issalig, 2022-01-02:
So, which cables are you analising, blk, whi, red from the indoor/outdoor unit.
Do you have an oscilloscope to check the real signal?

uploader18, 2022-01-02:
No, i am measuring directly on MCU RX and TX line
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
s

uploader18, 2022-01-04:
hey, i was thinking what if it is a SPI serial communication since by pulse waves it looks like full duplex communication and is uses 50hz as clock from power source, that would explain why pulses are 20ms wide.......??

issalig, 2022-01-04:
Hmm, but it there are olny 2 lines , then it would be i2c (SCL , SDA), does not it?
But the thing is that SPI and i2c are used to interconnect elements in a board, not to send it outdoor/large distances. Maybe you are just reading an element from the board (sensor maybe) that communicates with the main board.

Anyway, we are learning a lot. :)

uploader18, 2022-01-04:
When looking at PCB, transmiter and reciver are connected via optocouplers together and then data is sent over one wire. Clock is taken from 50hz mains on both sides indoor and outdoor unit so there is no need for clock wire.

issalig, 2022-01-05:
I wanted to say that SPI requires 4 lines SCLK, MISO, MOSI and SS so i2c makes more sense. However this 50hz signal is strange, normally it is just noise from the mains but data fits this clock signal.
Also from the decoding i2c has no sense to me because there are only addresses and not data. Typical i2c communication would be address+data, address+data, ...

uploader18, 2022-01-05:
I think that it is not pure spi but modified spi communication since MCU uses rx and tx lines and mains 50hz for clock.there is no need for SS pin since there is only master and one slave. For now i know that data sent from indoor unit(master) to outdoor(slave) is

Indoor umit capacity
Cooling or heating
Capacity demand
Indoor heat exchanger temperature

I think we are close.
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
uploader18, 2022-01-05:
capture RX TX CLOCK

[puls-clock_tx_rx.zip](https://github.com/issalig/toshiba_air_cond/files/7817052/puls-clock_tx_rx.zip)

issalig, 2022-01-06:
Yes, it seems a mix of SPI  (TX) and serial (RX)
but serial bytes have no sense to me. SPI bytes look better.

If seria-ish protocol I would expect one of the bytes to be datalength and present values in the range 0-10  and they are much bigger.

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

issalig, 2022-01-07:
Do you have any progress?

uploader18, 2022-01-07:
No, for now i will try to invert RX line.I think it is some kind of custom com protocol.You...any luck?

issalig, 2022-01-07:
No, it is completely different from the remote controller, :(

uploader18, 2022-01-08:
maybe this helps, MCU on the board is NEC 780076GK and communication is connected to TX2 and RX2.

issalig, 2022-01-11:
I checked the doc and it seems to combine UART and SPI in some manner.

Also, I found this document https://www.cdlweb.info/wp-content/uploads/2018/07/Installation-Manual-TCB-IFLN642TLE.pdf
It seems that protocol in outdoor units is called TCC-LINK. I thought this was the one I decoded for indoor units, but I was wrong and it is called sth like AB protocol

uploader18, 2022-01-11:
TCC-LINK is for remote control of VRV,VRF systems that uses modbus communication, same as your display and is open to public and uses U1,U2 or A,B terminal to communicate, on the other hand internal machine to machine protocol is different from any known protocol.

issalig, 2022-01-28:
I was playing with the last data you sent but did not get any good result and you?

issalig, 2022-04-07:
Any news on this? Should I close the issue and open it later if needed?

uploader18, 2023-01-28:
hey, good news, i figured it out but now i need help with checksum.

I get this data but no crc calculator works,

00 0F 00 34 00 21
10 5A 00 00 11 21
20 60 7F 53 00 1A
90 5A 00 00 11 20

Last byte is checksum i think?

Regards Žiga

issalig, 2023-01-28:
Nice, I am glad you solved it, will you document your work?

I have playing with a crc calculator but it does not give any reasonable values. Maybe your missing a byte? Also do not worry about crc, just read the important info and ignore crc.

uploader18, 2023-01-28:
ok so i managed crack that one too.

of you convert it to binary and count 0's in first 5 bytes you get checksum in last byte.

Regards Žiga

uploader18, 2023-01-28:
I cannot ignore checksum since i need it for two way communication.

issalig, 2023-01-28:
Great, how did you guess it?

uploader18, 2023-01-28:
just a lucky guess and trail and error like everything about this protocol, about documenting it is a little complicated since i don't think toshiba will be very happy about it and I can get a lawsuit for making it public. All of their outdoor units run on the same protocol, from first inverter AC to newest 2023 heat pump.What do you think?

issalig, 2023-01-28:
Well, as far you do not sell a product I do not see the problem.
But if you do not want to make it public, would it be ok for you to share the code with me? I am curious about what information is running from/to the outdoor unit.

uploader18, 2023-01-28:
indoor to outdoor
COMP. rev, TC sensor,TA sensor, heating/cooling, compressor on,error codes and indoor unit capacity

outdoor to indoor
actual COMP. rev, TE sensor,TO sensor,TD sensor,TS sensor, (heating/cooling, COMP on set confirmation), compressor current, defrost signal,error code, FAN rpm,PMV opening position, capacity code.

If you are willing to help me write arduino library for communication i will share all the data with you.

issalig, 2023-01-29:
I am just curious about the protocol. Last year I dedicated some hours to play with the data you provided and I would like to know how those signals were.

I can give you some hints about decoding it in arduino, moreover you have my code available to see how I solved it, this is the magic of open source :)

111lisu, 2023-11-17:
@uploader18 Hello, would there be a chance for codes for (starting / heating the exchanger) for the external unit?
A fraudster sold me a RAV-SP804ATP-E and was supposed to send the indoor unit. I called the service center and they said the costs were high.

milleroff, 2024-07-23:
Hi guys, any progress on this ?
I have several Toshiba RAS-M16GDV-E ducted ACs and based on the service manual they have the same serial protocol as you discussed in this thread.

What i want to achieve is to control the AC from an arduino (set mode & temp) but i don't want to use IR for that.
Or maybe you know a modbus or other protocol gateway that could work with this kind of ACs ? (they don't have the AB or U[1-4] terminals).

Thanks !

Closed 2022-06-28.

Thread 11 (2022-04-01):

PCB

anzejarni, 2022-04-01:
Hi there!
I am interested in the PCB. I might be able to help with the HA feature.

issalig, 2022-04-06:
Hi, I  can send you one soldered pcb with all the components for 8 EUR. Bare pcb would be 2 EUR.
Postage to Europe would be 2 EUR.

You can PM to  issalig    /AT/   yahoo _DOT_   es

issalig, 2022-04-15:
Still interested?

anzejarni, 2022-04-17:
Sorry for the late reply. Sent you an email today.

Closed 2022-04-17.

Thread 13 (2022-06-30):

Hi I have an internal Duct air conditioner Toshiba RAV-SM806BTP-E and I have a question for you in terms of managing it according to your scheme via Wi-Fi can help me with this

Axab2, 2022-06-30:
Hi I have an internal Duct air conditioner Toshiba RAV-SM806BTP-E and I have a question for you in terms of managing it according to your scheme via Wi-Fi can help me with this

Axab2, 2022-06-30:
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

Axab2, 2022-06-30:
Remote only wired to my disappointment

Axab2, 2022-06-30:
I would be glad if at least there was an opportunity to connect at least an IR receiver to the internal unit to control it with a wireless remote control.

Axab2, 2022-06-30:
I'm not talking about Wi-Fi at least an IR receiver

issalig, 2022-06-30:
My project decodes and adapts AB signal to serial 3.3V making it possible to decode/decode messages.

You could skip the Wifi part,and use an IR receiver but you would need a microcontroller such as ESP8266 or also an arduino nano could do the job.

In the board I designed there are still free I/O pins so you can hook a IR receiver.

Closed 2022-08-23.

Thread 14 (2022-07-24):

older model with 3 wires

olivluca, 2022-07-24:
Hello, I have an older model (around 30 years old) RAV-260BH/260AH8,  where the remote uses 3 wires: two for power supply (12 or 15v AC) and the remaining one for bidirectional communication. I don't have an oscilloscope, but since it uses a photo thyristor for sending and an optocoupler for receiving, I suppose it uses half of the ac wave for sending and the other half for receiving at 50bps.
This is what the service manual says
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
but it has no other details about the protocol used.
Finding information on this old unit is quite difficult, per chance do you happen to know something about it?

issalig, 2022-07-25:
Hi, I have no information about it. :(
The best way to guess what's happening is to use an oscilloscope. As you do not have one, maybe you can try with an arduino/esp8266 and the correspondent resistor divider (to convert voltages to to 0-5v for atmega or 0-3.3v for esp). Then with serial plotter from teh arduino IDE you can draw the values.
Also a logic analyzer would work, here it is an example https://aliexpress.com/item/1005003812410259.html

olivluca, 2022-07-25:
Thank you, if I weren't too scared to break the remote (since the spares are now unobtanium) I'd go with the plan b. I'll see if I can borrow an oscilloscope.

Closed 2022-07-25.

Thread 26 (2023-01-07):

Operating without a remote wired up? and PCB

hamishfagg, 2023-01-07:
Hi there,

The instructions for wiring your PCB say to wire it in parallel with a wired remote. Am I able to use just the PCB without also connecting a remote?

Also if you still have some PCBs I'm very interested in getting one :)

Thanks

issalig, 2023-01-08:
Hi, I have not tried it but afaik it would work. My pcb works independently and it does not depend on the official wire remote.

Yes, I still have some pcbs with components. Cost is 8 EUR + shipping. (I am based in EU)

hamishfagg, 2023-01-09:
Great, how can I contact you to get one shipped? :)

issalig, 2023-01-09:
you can write at issalig _AT- yahoo   _DOT-   es

Closed 2023-01-09.

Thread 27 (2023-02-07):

Send temperature from remote controller

hamishfagg, 2023-02-07:
Hi there,
Is your code able to send a temperature measurement from the remote (or from your PCB/wifi) to the indoor unit? I've had a look through the code and I don't think it's there but I might be missing it. Would it be hard to add?

issalig, 2023-02-07:
What do you mean? If it its possible to set a target temperature? If that's the question, the answer is yes aand it is done by function air_set_temp at
https://github.com/issalig/toshiba_air_cond/blob/9bd722440544486d960be91356f493cc87f417a3/air/toshiba_serial.hpp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

issalig, 2023-02-07:
Well, re-reading your message maybe you mean the status messages that remote sends to indoor unit like this one:
```
40 00 55 05 08 81 00 7C 00 E5 (heat mode 24)

40 00 55 05 08 81 00 68 00 f1
      |           |  |- 0110 1000 -> 104/2 -> 52 - 35 = 17   (temp)
      |-opc1         |-bit0 ON:1 OFF:0         
 ```

In such a case, you are true I have not function to build these messages. I just decode them because I used remote and my pcb together. A function for sending temp status would be like. Of course without wired controller you would need an external thermometer to read the date and set it to sensor_temp variable.
```
void air_send_status(air_status_t *air, uint8_t value)  {
  //             00    01    02    03    04    05    06    07    08    09    10    11   CRC
  byte data[] = {0x40, 0x00, 0x55, 0x05, 0x08, 0x81, 0x00, 0x7C, 0x00, 0xE5}; //dummy msg

  //send sensor temp
  data[7] = ((air->sensor_temp) + 35) << 1; //temp is bit7-bit1
  data[7] = data[7] + air->power; //set bit 0

  //compose new message
  //compute crc
  data[9] = XORChecksum8(data, sizeof(data) - 1);

  air_send_data(air, data, sizeof(data));
}
```

issalig, 2023-02-08:
If there is not remote and the pcb is alone, it would be necessary to have a ping function

```
void air_send_ping(air_status_t *air, uint8_t value)  {
  //             00    01    02    03    04    05    06    07    08   09   10    CRC
  byte data[] = {0x40, 0x00, 0x15, 0x07, 0x08, 0x0C, 0x81, 0x00, 0x00, 0x48, 0x00, 0x9F}; //dummy msg

  //compose new message
  //compute crc
  data[11] = XORChecksum8(data, sizeof(data) - 1);

  air_send_data(air, data, sizeof(data));
}
```

hamishfagg, 2023-02-09:
Thank you for all of your tips on this! I will have a go at it when I have some time.

hamishfagg, 2023-04-11:
I've discovered when trying to install my PCB that my heatpump is missing several components on the AB terminal board (most notably a transformer) so unfortunately I can't install it. But thanks for your help!

issalig, 2023-04-11:
Ooops. Could you post a photo? Maybe there is an easy fix.

Closed 2023-04-11.

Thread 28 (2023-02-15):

toshiba_air_cond instead remote controller?

MrTheBarbarian, 2023-02-15:
Hello!
Great job you have done!
Is it possible to use this device instead remote controller?
I have ordered Estia R32 heat pump, but I didn't order remote controller. I thought is it possible to control the heat pump remotely with this device if I do not have remote controller.
Thanks!

issalig, 2023-02-15:
I have not tried it but I think it is possible.
Probably the only thing you need is to periodically report the temperature (you will need also a temperature sensor) with the function mentioned in this issue https://github.com/issalig/toshiba_air_cond/issues/27#issuecomment-1420507111

Titoflegit, 2025-01-09:
I made some measurements on the AB bus of my toshiba estia serie 3 heatpump.
Electrical levels are almost the same but a bit higher at 16.5 volts /14volts, baudrsye at 2400 but without parity. Then the messages are completely differrent there is a fixed frame without response each 5 seconds beginning with F0F0 and ending with A0. And if we change something on the controller this frame is longer but still ending with A0 so there is no more a CRC.

Titoflegit, 2025-01-09:
Estia Series 3. Controller HWS AMS11E
Periodic Frame without response each 5 seconds.
F0F00A70FFFF003AB2A0

Frame sended when temperature changed to 45 degrees:
F0F00F6070E00123027A668A7AC9A0
Acknowledged with:
F0F00A7060E080A1DBA0

Frame sended when temperature changed to 44 degrees:
F0F00F6070E00123027**8**668A7**8**C**5**A0 (changes in **BOLD** vs 45 degres)
Acknowledged with:
F0F00A7060E080A1DBA0 (same as 45 degrees)

Frame sended when temperature changed to 43 degrees:
F0F00F6070E00123027**6**668A7**6**C**1**A0 (changes in **BOLD** vs 45 degres)
Acknowledged with:
F0F00A7060E080A1DBA0 (same as 45 degrees)

There is also sometimes some other frames that are exchanged without pressing any button on the controller, so we cannot simply emulate the controller. I doubt also that the temperature change frame will be the same in the case of the addition of a second remote controller and don't want to spend 300EUR to make measurments.

From series 4 and 5 (and also R32 I suppose) there is a ABbus to Modbus interface available, at also 300EUR but it would be the simplest solution I think.

For me, I will go the plan B, i.e. optocoupler to act like the pushbutton is pressed, or less invasive plan B2 with some electromagnet pressing the buttons, but only practical for a few buttons, perhaps only the temperature)

Hope to have contributed. I you think that some scope screenshots can be usefull, jsut ask, the setup si still in place

Titoflegit, 2025-01-09:
Regarding your backup plan to emulate button pressure with optocouplers, how did you proceed to locate the vias to short with the optocoupler ?

issalig, 2025-01-09:
Visually follow the trace of the two parts of the button footprint, then stop at a via (where you can solder). Double check it with a tester (beep in diode checking mode).

issalig, 2025-01-09:
> Estia Series 3. Controller HWS AMS11E Periodic Frame without response each 5 seconds. F0F00A70FFFF003AB2A0
>
> Frame sended when temperature changed to 45 degrees: F0F00F6070E00123027A668A7AC9A0 Acknowledged with: F0F00A7060E080A1DBA0

Great, did you manage to decode the protocol?
If not, I can take a look next week.

> Hope to have contributed. If you think that some scope screenshots can be usefull, jsut ask, the setup is still in place
Yes, feel free to add screenshots that document it.
Thanks!

issalig, 2025-01-09:
About the collision, I would not worry about it. Just send messages twice :)

issalig, 2025-01-10:
Some progress, F0F0  (1111 0000 1111 0000) and A0 (1010 0000) are normally used as start of frame and end of frame markers.
```
F0 F0 0F 60 70 E0 01 23 02 7A 66 8A 7A C9 A0
                                          |- end
                                       |- CRC
                                    |- temp*2 +32
                              |- 66 8A could be mode or speed
                           |- repeated temp?
               |- E0 is common byte
            |- dest 70 is master, FF is everybody?
         |- source  60 is remote
|- begin
```

Temperature seems to follow this rule.
protocol_value = (temperature × 2) + 32
45°C: (45 × 2) + 32 = 122 (0x7A)
Temperature is repeated, do not why

66 8A seem to be mode

CRC is used and is the last byte but one.
CRC is computes as the sum of the bytes without markers modulo 256

0F + 60 + 70 + E0 + 01 + 23 + 02 + 7A + 66 + 8A + 7A = 3C9
3C9 mod 256 = C9

Can you change the mode, fan speed, save, etc, ... and post the messages?

Titoflegit, 2025-01-10:
So situation at start is heating zone 1 active in autotemp mode, hot water disabled.
Following the frames are witjout the starting F0F0 and the endind A0
Sometimes as described before there is a status ?? sended. longer thant the ping ?? each 5 seconds, I name t a PeriodicLong.

So PeriodicLong:
0F6070E0410C8100004800D5
Turn off Autotemp mode, actual temp setting is 35°
0C6070E001240100E2
PeriodicLong
0F6070E0410C8100004800D5
Turn on Autotemp
0C6070E001240101E3
Turn off Zone heating
0B6070E0012902DF
Turn on Zone heating
0B6070E0012103E0
Turn On Hot water watertemp settings was 55°
0B6070E001210CE9
Water temp to 50°,(no trace)  then Hot water off
0B6070E06131004D
WATER ON
0B6070E001210CE9 (so temperature setting is not in the command)
Hot water temp down to 49°
OF6070E0012308666681669F
PeriodicLong
0F6070E410C8100004800D5
Hot water temp down to 48°
OF6070E00123086666A0669D
Hot water temp down to 47°
OF6070E001230866667E669B
Periodic:Long
0F6070E0410C8100004800D5
Hot Water OFF
0B6070E0012108E5
Night Mode ON
0C6070e01324880871
Night Mode OFF
0C6070E00124A80069
Now we are back in autotemp mode as at the start.

issalig, 2025-01-10:
```
Opcode 0C

F0 F0 0C 60 70 E0 01 24 01 01 E3 A0
                           |- 0 OFF 1 ON  Autotemp

Opcode 0B

F0 F0 0B 60 70 E0 01 21 08 E5 A0
                        |- 0C (1010) ON 08 (1000) OFF  Hot water  -> bit 1 and bit 3?
F0 F0 0B 60 70 E0 01 21 03 E0 A0
                        |- 3 (0011) ON 2 (0010)  OFF  Zone heating  bit0,   bit1 is always set

Opcode 0F
F0 F0 0F 60 70 E0 01 23 08 66 66 81 66 9F A0
                                 |-(129-32)/2 = 48.5 water temp ???
F0 F0 0F 60 70 E0 01 23 08 66 66 7E 66 9B A0
                                 |-(126-32)/2 = 47 water temp
                              |-(0x66-32)/2 = 35 current temp setting
                         
We already know
F0 F0 0F 60 70 E0 01 23 02 7A 66 8A 7A C9 A0
__ __ __ __ __ __ ?? ?? ?? __ ?? ?? __ __ __
                                          |- end
                                       |- CRC
                                    |- temp*2 +32
                              |- 66 8A could be mode or speed?/ another temp?
                           |- repeated temp?
               |- E0 is common byte
            |- dest 70 is master, FF is everybody?
         |- source  60 is remote
       |- length
|- begin

```
So we add

Titoflegit, 2025-01-11:
F0 F0 0F 60 70 E0 01 23 02 7A 66 8A 7A C9 A0
__ __ __ __ __ __ ?? ?? ?? __ ?? ?? __ __ __
                                          |- end
                                       |- CRC
                                    |- temp*2 +32
                              |- 66 8A could be mode or speed?/ another temp?
                           |- repeated temp?
               |- E0 is common byte
            |- dest 70 is master, FF is everybody?
         |- source  60 is remote
       |- length
|- begin

8A is perhaps hot water temperature 53 degrees

issalig, 2025-01-11:
To sum up.

```
Periodic message from remote to master, status?
F0 F0 0F 60 70 E0 41 0C 81 00 00 48 00 D5 A0

F0 F0 0A 70 FF FF 00 3A B2 A0 //pulse every 5s  master to all
F0 F0 0A 70 60 E0 80 A1 DB A0 //ack from master

-------
Autotemp
F0 F0 0C 60 70 E0 01 24 01 01 E3 A0
                           |- 0 OFF 1 ON  Autotemp

-------
Hot water
F0 F0 0B 60 70 E0 01 21 08 E5 A0
                        |- 0C (1010) ON 08 (1000) OFF  Hot water  -> bit 1,  bit 3 is always set ??

Zone heating
F0 F0 0B 60 70 E0 01 21 03 E0 A0
                        |- 3 (0011) ON 2 (0010)  OFF  Zone heating  bit0,   bit1 is always set ??

-------
F0 F0 0F 60 70 E0 01 23 02 7A 66 8A 7A C9 A0
__ __ __ __ __ __ ?? ?? ?? __ __ __ __ __ __
                                          |- end
                                       |- CRC sum of bytes without (F0F0 and CRC A0) % 256
                                    |- temp*2 +32  7A -> 45º
                                 |- 8A -> 53º water temp
                              |- 66 -> 35º other temp
                           |- 8A -> 53º repeated temp after 3 bytes?
                   |- 01 23 02 unknown                   
               |- E0 is common byte
            |- dest 70 is master, FF is everybody?
         |- source  60 is remote
       |- length
|- begin

```

issalig, 2025-01-19:
Any progress? @Titoflegit

Titoflegit, 2025-01-19:
I wait on the usb to serial TTL converter delivery so I will be able to sniff with my laptop and make some trials to send frames and see if they are accepted. Will keep you informed

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

issalig, 2025-01-19:
What are you going to use for communication? My circuit and a ttl to usb?

Titoflegit, 2025-01-19:
Yep. Without the optocoupler. I did not find the way to interface correctly to the rs485 usb converter I have already

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

issalig, 2025-01-20:
you can use a simple usb ttl adapter https://aliexpress.com/item/32637261853.html which I think is the one you are waiting for.

Also  you can try an ESP8266, or even an arduino

Titoflegit, 2025-01-30:
So I use your circuit and a ttl usb converter, I engraved a little pcb on my cnc milling maching and soldered it yesterday.

But there is problem, the rx line is in the wrong polarity, normally idle is high and with your circuit it is not rhe case. Did I miss something?

I will correct it by cabling the opto toward gnd rather than vcc.

Hope it will work.

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

issalig, 2025-01-30:
Hmm, if you disconnect AB wires you still get "1" ?

Titoflegit, 2025-01-30:
Yesterday I got idle voltage on rx at around 2v and the datastream as positive pulses to 3v3.

But I agree that it is not according your schematics where the opto light when voltage is zener + Vf doode + Vf opto ..

I will check tje voltage threshold with a lab voltage source

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

issalig, 2025-01-30:
As a dirty trick you can add one more diode such as 1n4001, to drop another 0.7v

I am not an electronics expert, just self-learner, I have seen others using opamps and that is probably a better solution than the zener workaround.

Titoflegit, 2025-01-30:
In fact there was 2 problems the threshold that I solved by changing the zmm13 by a 5v6 and 8v2 in series and also the low level volrage because the usbttl adapter has a led directly on the rx so your 1k was too high to have a valid low signal...

Nevertheless your design has the best advantage Simplicity!!

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

Titoflegit, 2025-01-30:
Ok it works and my python script sniff it. With SOF end EOF removed.

This is doing nothing on the remote control, mode is zone 1 in automatic
mode, DHW off

What are your suggestions for the next steps?

-----------------------------------

Starting new event loop
main sniffer task started
2025-01-30 16:42:07,476 Serial Port is now opened
2025-01-30 16:42:07,476 Opening serial interface:
  port: COM3
  baudrate: 2400
  bytesize: 8
  parity: none
  stopbits: 1
  timeout: 0.01375
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

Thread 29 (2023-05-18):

I'm interested in PCB

krishy2, 2023-05-18:
Hello,

I own a Toshiba Estia heat pump. I'd like to assume it has the same "AB" bus. Do you have any experience? Otherwise I'd give a try, just for fun.

Thanks!

issalig, 2023-05-19:
Hi, I do not know Estia system, but it would be nice if you can explore it.
I can send you one soldered pcb with all the components for 8.5 EUR. Bare pcb would be 2 EUR.

Postage to Europe would be 2 EUR for untracked.

Tell me which option do you prefer and the destination country.

alsig, 2023-05-19:
Hey.

 I also have a Toshiba Estia heatpump.

Do you have more mounted PCBs in stock? Destination country: Denmark

/Jens

issalig, 2023-05-19:
Yes. I have the components, so I can mount them in a couple of days.

Also, take into account that I do not know if my PCB is compatible with Estia.

krishy2, 2023-05-19:
Hey,
Country: HU
Details: kamuzokrishy at gmail

I understand that you are not sure if it works with Estia, but we will figure it out.

alsig, 2023-05-20:
Super!

Country: Denmark
Details: alsig [at] alsig [dot] dk

issalig, 2023-05-22:
PM sent.

krishy2, 2023-05-22:
Hi,
Something went wrong, I have nothing in my mailbox :(

alsig, 2023-06-04:
Hi,

Just a bit of feedback.

I've received the PCB two days ago, installed right away and the PCB is working with an Esti heat pump! Great work!

I haven't verified the software yet only the hardware.

I used ESPhome with the following recipe:
```
esphome:
  name: toshiba-link
  friendly_name: toshiba_link

esp8266:
  board: d1_mini

# Enable logging
logger:

# Enable Home Assistant API
api:
  encryption:
    key: "magic key :)"

ota:
  password: "top secret password"

wifi:
  ssid: !secret wifi_ssid
  password: !secret wifi_password

  # Enable fallback hotspot (captive portal) in case wifi connection fails
  ap:
    ssid: "Toshiba-Link Fallback Hotspot"
    password: "Yet another password"

captive_portal:

uart:
  tx_pin: D8
  rx_pin: D7
  baud_rate: 2400
  parity: EVEN
  debug:
    direction: RX
    dummy_receiver: true
    after:
      timeout: 100ms
    sequence:
      - lambda: UARTDebug::log_hex(uart::UART_DIRECTION_RX, bytes, ':');
```

So @issalig thank you!
/alsig

krishy2, 2023-06-04:
I am curious about it!
My office sent me the message that we received it, but I’m working in Africa, so I’ll be at home in 2 weeks.

Please keep me updated!
I’ll try to integrate as well.

Do you have any plan to have a web interface or smartphone app also?

Thanks,
Kris

Tóth Kristóf
Ügyvezető
Tel.: +36-30-2218678
Control Pro Kft.
Irányítástechnikai Tervező és Kivitelező Kft.
1021 Budapest, Ötvös János u. 3.
________________________________
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

issalig, 2023-06-05:
Nice, I have not tried ESPHome, in fact I did not know someone had added support for toshiba. I will take a look.

From my side, I have a web interface that resides in the eps8266.
https://github.com/issalig/toshiba_air_cond#software-installation
and it can be found at
https://github.com/issalig/toshiba_air_cond/tree/master/air/data

alsig, 2023-06-05:
Well there isn't support in esphome, yet.
All i did was to make a datalogger in esphome.
I'm hoping that I'll be able to add support to esphome for my heat pump.
/alsig

issalig, 2023-06-05:
Feel free to open an issue to report your progress with esphome. Then I could add a small guide in the main page.

krishy2, 2023-06-05:
Do we know the datagrams of Estia? Or maybe they are the same as other Toshiba products?

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

alsig, 2023-06-05:
What I can see from the data is the protocol isn't quite the same. There are similarities but the source and destination adresses are different, the checksum calculation doesn't match your implantation and the temperature conversion are also using a different equation...

issalig, 2023-06-05:
It would be great if you manage to guess the protocol. If you have doubts, just paste the bytes and I can try to guess what´s going on. I tried to document it how I decoded it (main page of repo) but maybe it is not as clear as I though.

You could just ignore crc (at least for RX) . Also you can try https://www.scadacore.com/tools/programming-calculators/online-checksum-calculator/

alsig, 2023-06-05:
Good evening.

I have had some success last night and tonight.

It looks like they have modified the protocol a bit. Here is what I have learned so far.

It looks like the remote control has address 0xA0 and the master has address 0x00.
The status command is 0x1C and ping/alive is 0x10. All (source, destination, opcode-1 and length) are 8 bits.
A padding(?) bytes have been inserted in position 4 (zero indexed) and the read/write byte is in position 6.
The checksum is actually a crc16 (info here: https://crccalc.com/?crc=A0001C0F00080000FE03C6C30010845C660000&method=CRC-16/MCRF4XX&datatype=hex&outtype=0)

I also discovered that the temperature calculations are done like this:
hex_value = temp_deg_c * 2 + 0x20

I have attached a long file for those of you who are curious.

[logs_toshiba-link_logs_with_timestamps.txt](https://github.com/issalig/toshiba_air_cond/files/11657085/logs_toshiba-link_logs_with_timestamps.txt)

issalig, 2023-06-05:
Great, it works for the messages starting with A0 but it does not work the others, for example:
 AF:FB:55:C9:FF:DB:7F:CB:FE:FB:F6:FF:B7: (AF:6F) should be  DC:11

alsig, 2023-06-06:
Damn it :/ Oh well back to the drawing board

issalig, 2023-06-09:
I have tried reveng to guess the CRC algorithm without success https://reveng.sourceforge.io/

issalig, 2023-07-19:
Hi, did you finally manage to decode it?

alsig, 2023-07-19:
Kind of... I did manage to decode part of the protocol but then I got cough up at work and then summer hit... I get back to the project at autumn time. I'll keep you updated...

krishy2, 2023-11-14:
Hello Guys,

Is there any update at your side?

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

issalig, 2023-11-14:
I wanted to integrate it with homeassistant but I have not tried yet :)

krishy2, 2023-11-14:
But the protocol is clear?

In fact, I’d like to change between two modes in my house at the countryside.

  1.  Most of the times I’m away and I want to have 15C VLT just for frost protection. This would allow the best COP.
  2.  When I’m in the house I need the 45C VLT to ramp it up, later 30-35C is ok.

So, I need to change the VLT continuously.  I haven’t found any possibility to achieve this by digital inputs. Even the modbus converter hasn’t Ethernet or wifi, but costs almost 600€.

If the protocol works, I could issue the VLT set command at least. HA can wait 😊

Thanks

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

issalig, 2023-11-14:
I was referring to my unit not Estias, so nothing from my side.

krishy2, 2023-11-16:
I’d kill for a Modbus coupler 😊 in that case we could sniff the data.

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

Closed 2024-08-09.

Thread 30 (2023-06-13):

Interested also in PCB :)

Moshiker, 2023-06-13:
Hi,
I'm interested also in one soldered PCB with all the components ready for use.
how can I contact you?

Moshik

issalig, 2023-06-14:
Ok, pass me you email and I will contact you.

MoshikBarak, 2023-06-14:
MoshikBarak at g m a i l . c o m

Closed 2024-08-09.

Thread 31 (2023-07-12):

Interested in PCB

Muschu, 2023-07-12:
Im interested in a pcb and more Details 😀

issalig, 2023-07-14:
Ok, pass me you email and I will contact you.
You can write it here and I will delete it as soon as I read it.

Closed 2024-08-09.

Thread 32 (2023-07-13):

Interested in PCB as well.

sebastianPsm, 2023-07-13:
Hey,

pretty cool project. Do you still have a board for me?

Best greetings
Sebastian

issalig, 2023-07-14:
Ok, pass me you email and I will contact you.
You can write it here and I will delete it as soon as I read it.

sebastianPsm, 2023-07-15:
Hey,

My mail address is sebastianpsm@googlemail.com. You can write me in German or English language.

Looking forward to hear from you

Best greetings
Sebastian

Closed 2024-08-09.

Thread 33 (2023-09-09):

Unknown messages

stoffelll, 2023-09-09:
Hi,
I'm using https://github.com/pedobry/esphome_toshiba_suzumi/tree/main and communicating via wifi with my toshiba aircon.

There is a feature integrated to scan for unknown messages/sensors and I got some unknown messages.
I'm now looking for the power consumption of my unit, maybe you have an idea if it is inside of this messages?

This are my messages when the aircon is switched of -> idle mode:
`[07:30:00][I][ToshibaClimateUart:125]: Requesting data from sensor 253, checksum: 183
[07:30:00][I][ToshibaClimateUart:125]: Requesting data from sensor 254, checksum: 182
[07:30:00][W][component:204]: Component api took a long time for an operation (0.98 s).
[07:30:00][W][component:205]: Components should block for at most 20-30ms.
[07:30:00][I][ToshibaClimateUart:271]: Received AC unit power state: OFF
[07:30:00][W][ToshibaClimateUart:291]: Unknown sensor: 129 with value 0
[07:30:00][W][ToshibaClimateUart:215]: Received unknown message with length: 20 and value 02.00.03.90.00.00.0C.01.30.01.00.00.00.05.82.00.01.00.00.A7 (20)
[07:30:00][W][ToshibaClimateUart:215]: Received unknown message with length: 25 and value 02.00.03.90.00.00.11.01.30.01.00.00.00.0A.86.05.00.00.17.00.00.00.00.00.7E (25)
[07:30:00][I][ToshibaClimateUart:263]: Received power select: 100
[07:30:00][W][ToshibaClimateUart:291]: Unknown sensor: 136 with value 66
[07:30:00][W][ToshibaClimateUart:215]: Received unknown message with length: 18 and value 02.00.03.90.00.00.0A.01.30.01.00.00.00.03.89.00.00.A5 (18)
[07:30:00][W][component:204]: Component toshiba_suzumi.climate took a long time for an operation (0.08 s).
[07:30:00][W][component:205]: Components should block for at most 20-30ms.
[07:30:01][W][ToshibaClimateUart:291]: Unknown sensor: 144 with value 66
[07:30:01][W][ToshibaClimateUart:215]: Received unknown message with length: 18 and value 02.00.03.90.00.00.0A.01.30.01.00.00.00.03.92.00.00.9C (18)
[07:30:02][W][ToshibaClimateUart:291]: Unknown sensor: 148 with value 66
[07:30:02][W][ToshibaClimateUart:215]: Received unknown message with length: 18 and value 02.00.03.90.00.00.0A.01.30.01.00.00.00.03.96.00.00.98 (18)
[07:30:02][W][ToshibaClimateUart:215]: Received unknown message with length: 21 and value 02.00.03.90.00.00.0D.01.30.01.00.00.00.06.9A.00.00.00.00.00.8E (21)
[07:30:03][I][ToshibaClimateUart:232]: Received fan mode: Level 5
[07:30:03][I][ToshibaClimateUart:239]: Received swing mode: OFF
[07:30:05][I][ToshibaClimateUart:245]: Received AC mode: COOL
[07:30:05][I][ToshibaClimateUart:220]: Received target temp: 21
[07:30:05][W][ToshibaClimateUart:291]: Unknown sensor: 180 with value 50
[07:30:06][W][ToshibaClimateUart:215]: Received unknown message with length: 18 and value 02.00.03.90.00.00.0A.01.30.01.00.00.00.03.B9.00.00.75 (18)
[07:30:06][W][ToshibaClimateUart:291]: Unknown sensor: 186 with value 0
[07:30:06][I][ToshibaClimateUart:252]: Received room temp: 24 °C
[07:30:06][I][ToshibaClimateUart:257]: Received outdoor temp: 16 °C
[07:30:06][W][ToshibaClimateUart:291]: Unknown sensor: 192 with value 0
[07:30:07][W][ToshibaClimateUart:291]: Unknown sensor: 198 with value 0
[07:30:07][W][ToshibaClimateUart:291]: Unknown sensor: 199 with value 16
[07:30:08][W][ToshibaClimateUart:291]: Unknown sensor: 203 with value 16
[07:30:09][W][ToshibaClimateUart:215]: Received unknown message with length: 18 and value 02.00.03.90.00.00.0A.01.30.01.00.00.00.03.DB.00.00.53 (18)
[07:30:10][W][ToshibaClimateUart:291]: Unknown sensor: 223 with value 0
[07:30:12][W][ToshibaClimateUart:215]: Received unknown message with length: 18 and value 02.00.03.90.00.00.0A.01.30.01.00.00.00.03.EE.2C.00.14 (18)
[07:30:13][I][ToshibaClimateUart:284]: Received special mode: 0
[07:30:13][W][ToshibaClimateUart:215]: Received unknown message with length: 20 and value 02.00.03.90.00.00.0C.01.30.01.00.00.00.05.F8.42.15.36.00.A5 (20)
[07:30:13][W][ToshibaClimateUart:291]: Unknown sensor: 254 with value 48
[07:30:22][I][ToshibaClimateUart:125]: Requesting data from sensor 187, checksum: 249
[07:30:22][I][ToshibaClimateUart:125]: Requesting data from sensor 190, checksum: 246
[07:30:22][I][ToshibaClimateUart:252]: Received room temp: 24 °C
[07:30:22][I][ToshibaClimateUart:257]: Received outdoor temp: 16 °C`

Thanks for your guidance!

stoffelll, 2023-09-09:
This is the log when the aircon is in cooling mode and switched on:

[07:33:56][I][ToshibaClimateUart:271]: Received AC unit power state: ON
[07:33:56][W][ToshibaClimateUart:291]: Unknown sensor: 129 with value 0
[07:33:56][W][ToshibaClimateUart:215]: Received unknown message with length: 20 and value 02.00.03.90.00.00.0C.01.30.01.00.00.00.05.82.00.01.00.00.A7 (20)
[07:33:56][W][ToshibaClimateUart:215]: Received unknown message with length: 25 and value 02.00.03.90.00.00.11.01.30.01.00.00.00.0A.86.05.00.00.17.00.00.00.00.00.7E (25)
[07:33:56][I][ToshibaClimateUart:263]: Received power select: 100
[07:33:56][W][ToshibaClimateUart:291]: Unknown sensor: 136 with value 66
[07:33:56][W][ToshibaClimateUart:215]: Received unknown message with length: 18 and value 02.00.03.90.00.00.0A.01.30.01.00.00.00.03.89.00.00.A5 (18)
[07:33:56][W][component:204]: Component toshiba_suzumi.climate took a long time for an operation (0.08 s).
[07:33:56][W][component:205]: Components should block for at most 20-30ms.
[07:33:57][W][ToshibaClimateUart:291]: Unknown sensor: 144 with value 66
[07:33:57][W][ToshibaClimateUart:215]: Received unknown message with length: 18 and value 02.00.03.90.00.00.0A.01.30.01.00.00.00.03.92.00.00.9C (18)
[07:33:57][W][ToshibaClimateUart:291]: Unknown sensor: 148 with value 66
[07:33:57][W][ToshibaClimateUart:215]: Received unknown message with length: 18 and value 02.00.03.90.00.00.0A.01.30.01.00.00.00.03.96.00.00.98 (18)
[07:33:58][W][ToshibaClimateUart:215]: Received unknown message with length: 21 and value 02.00.03.90.00.00.0D.01.30.01.00.00.00.06.9A.00.00.00.00.00.8E (21)
[07:33:59][I][ToshibaClimateUart:232]: Received fan mode: Level 5
[07:33:59][I][ToshibaClimateUart:239]: Received swing mode: VERTICAL
[07:34:00][I][ToshibaClimateUart:245]: Received AC mode: COOL
[07:34:01][I][ToshibaClimateUart:220]: Received target temp: 21
[07:34:01][W][ToshibaClimateUart:291]: Unknown sensor: 180 with value 50
[07:34:01][W][ToshibaClimateUart:215]: Received unknown message with length: 18 and value 02.00.03.90.00.00.0A.01.30.01.00.00.00.03.B9.00.00.75 (18)
[07:34:02][W][ToshibaClimateUart:291]: Unknown sensor: 186 with value 0
[07:34:02][I][ToshibaClimateUart:252]: Received room temp: 24 °C
[07:34:02][I][ToshibaClimateUart:257]: Received outdoor temp: 17 °C
[07:34:02][W][ToshibaClimateUart:291]: Unknown sensor: 192 with value 0
[07:34:03][W][ToshibaClimateUart:291]: Unknown sensor: 198 with value 0
[07:34:03][W][ToshibaClimateUart:291]: Unknown sensor: 199 with value 16
[07:34:03][W][ToshibaClimateUart:291]: Unknown sensor: 203 with value 16
[07:34:05][W][ToshibaClimateUart:215]: Received unknown message with length: 18 and value 02.00.03.90.00.00.0A.01.30.01.00.00.00.03.DB.00.00.53 (18)
[07:34:06][W][ToshibaClimateUart:291]: Unknown sensor: 223 with value 0
[07:34:07][W][ToshibaClimateUart:215]: Received unknown message with length: 18 and value 02.00.03.90.00.00.0A.01.30.01.00.00.00.03.EE.2C.00.14 (18)
[07:34:08][I][ToshibaClimateUart:284]: Received special mode: 0
[07:34:08][W][ToshibaClimateUart:215]: Received unknown message with length: 20 and value 02.00.03.90.00.00.0C.01.30.01.00.00.00.05.F8.42.15.36.00.A5 (20)
[07:34:09][W][ToshibaClimateUart:291]: Unknown sensor: 254 with value 48

issalig, 2023-09-09:
My AC looks different (it had no wifi, only wired interface)
In my AC I need to query a sensor with the given id
https://github.com/issalig/toshiba_air_cond/blob/09efcf16fcfe43d4e7dd11c5d2141aaf0082e5ac/air/toshiba_serial.hpp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
Then, read the sensor status https://github.com/issalig/toshiba_air_cond/blob/09efcf16fcfe43d4e7dd11c5d2141aaf0082e5ac/air/toshiba_serial.hpp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

In particular in my system current sensor id is 0x6A  https://github.com/issalig/toshiba_air_cond/blob/09efcf16fcfe43d4e7dd11c5d2141aaf0082e5ac/air/toshiba_serial.h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

Hope this helps!

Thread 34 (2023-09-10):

Working with SKV range of products?

studiostevus, 2023-09-10:
Would this work with the Toshiba SKV range of products?

RAS-137SKV-E7

issalig, 2023-09-11:
If there is an internal AB connector it would probably work.
My project is for wired remotes, not sure if this model supports them.

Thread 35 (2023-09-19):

Interested in a PCB/Gerber files

Etacovda, 2023-09-19:
Hi there,

This look suitable for my r410a series 4 estia - could i get a pcb/files? thanks very much

issalig, 2023-09-19:
Of course, they are available at https://github.com/issalig/toshiba_air_cond/blob/master/pcb/airpcb_smd/gerber.zip

Also the Kicad files are available, feel free to modify it an to improve it and of course to share it!

Closed 2023-11-08.

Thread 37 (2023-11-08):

Outdoor unit control RAV 8kW

111lisu, 2023-11-08:
I need to control Outdoor unit control, I don't have an indoor unit, is there any chance to scan the codes or something like that. the outdoor unit is connected to the gas water plate heat exchanger

issalig, 2023-11-08:
I do not have info about outdoor units. See issues https://github.com/issalig/toshiba_air_cond/issues/10 and https://github.com/issalig/toshiba_air_cond/issues/14, maybe you can get some info from there.

111lisu, 2023-11-08:
thx

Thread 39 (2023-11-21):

Interested in 3 x pcb's if possible?

prowebuk, 2023-11-21:

iti-praia, 2023-11-21:
Hi, I'm glad you are interested in the project.
I can send you one soldered pcb with all the components for 8.5 EUR. Bare pcb would be 2 EUR.

Postage to Europe would be 3 EUR for untracked, 8 EUR for tracked.

Tell me which option do you prefer and the destination country.

issalig, 2023-11-21:
Hi, I'm glad you are interested in the project.
I can send you one soldered pcb with all the components for 8.5 EUR. Bare pcb would be 2 EUR.

Postage to Europe would be 3 EUR for untracked, 8 EUR for tracked.

Tell me which option do you prefer and the destination country.

prowebuk, 2023-11-22:
Hi,

Can I order 3 x soldered pcb with all the components for 8.5 EUR = 25.50 Euro plus tracked postage @ 8 Euro

My PayPal address is ***@***.******@***.***> if you want to send an invoice?

Address is:

Richard Drage
Proweb (UK) Ltd
Rutland Suite
St James Business Park
Radcliffe on Trent
Nottingham
NG12 2JP
UK

Many thanks

Richard

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

issalig, 2023-11-22:
Ok, give me your email address and I will MP you.

prowebuk, 2023-11-22:
Paypal is ***@***.******@***.***>, not sure what MP is?

Thanks

Richard

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

issalig, 2023-11-23:
Sorry, I wanted to say PM (private message).

For some reason I cannot see your address it is shown like this ***@***.******@***.***

Maybe you can try with    your_name AT   your_domain DOT com

prowebuk, 2023-11-23:
😊 my email is richard at proweb dot net

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

Closed 2024-08-09.

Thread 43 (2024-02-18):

interested in 4 pcbs - can you send them to the Czech Republic?

martinskokan, 2024-02-18:
I came across your project and I would like to control the RAS Multisplit system with 4 indoor units.
would you be so kind and send me the PCBs? payment can be done either through paypal or using direct SEPA transfer

thank you
Martin

issalig, 2024-02-18:
Do you want just the pcb or also pcb with the components soldered?

martinskokan, 2024-02-18:
complete with the components please. thanks a lot

ne 18. 2. 2024 v 21:25 odesílatel issalig ***@***.***> napsal:

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

Closed 2024-08-09.

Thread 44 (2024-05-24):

populated PCBs

Etacovda, 2024-05-24:
Hi there, I was wondering if you're still doing the populated pcbs?

Thanks,

issalig, 2024-05-27:
Hi, I still have 2 units available.

LuukML, 2024-06-23:
Hey, did you sell them already? Im in the netherlands can I order one for testing? Is it esp32?

mateuszdrab, 2024-07-07:
> Hi, I still have 2 units available.

I'd like one too

issalig, 2024-08-09:
Sorry guys, I do not longer provide pcbs. But you can get them from jlcpcb.com

Closed 2024-08-09.

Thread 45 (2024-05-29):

Interested in 4 PCBs

shing6326, 2024-05-29:
Hello, thanks for the great project, I would like to get 4 PCBs for my Toshiba AC, I am located in Singapore.

issalig, 2024-06-11:
Hi, sorry for the delay.

I only have 2 pcbs available but they are just bare pcbs without components.

shing6326, 2024-06-13:
Thanks @issalig

Bare pcbs is fine, I could solder it by myself. May I know if I could have the BOM and CPL files as well for purchasing the components? Feel free to communicate privately with my email for the purchase. Look forward :)

shing
b8452524664@shing.cloud

Closed 2024-06-18.

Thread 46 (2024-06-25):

Interested in 2 populated PCB

Dieghito72, 2024-06-25:
Hi, I'm interested in 2 populated PCB to be shipped to Italy.

issalig, 2024-08-09:
Sorry, I do not longer provide pcbs. But you can get them from jlcpcb.com

issalig, 2025-05-27:
Hi, it's been a long time and you probably have made your own pcbs but I have found in a drawer 2 spare boards in case you are interested.

Dieghito72, 2025-05-27:
> Hi, it's been a long time and you probably have made your own pcbs but I have found in a drawer 2 spare boards in case you are interested.

Hi! To be honest I'm not so skilled on the electronic parts to go on myself on this, so I'm still interested.

issalig, 2025-05-27:
Ok, nice. Write me to syxal@tafmail.com and I will give you the details.

Closed 2024-08-09.

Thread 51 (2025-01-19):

RBC-AMS55E reporting 01 as master and not 00 as expected

issalig, 2025-01-19:
### Discussed in https://github.com/issalig/toshiba_air_cond/discussions/50

<div type='discussions-op-text'>

<sup>Originally posted by **Gerhard1968** January 19, 2025</sup>
Hello friends, i build the project with the pcb from issalig and connect to my wall controller RBC-AMS55E. I can read the codes on the web side. It shows me the same setting of the RBC-AMS55E on the webside, but its not able to send the commands from webside to the RBC-AMS55E.
Its a different protocol? I see it´s a little differenc in the first and last bit.
And sorry about my bad english!

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
</div>

issalig, 2025-01-19:
Interesting, it seems that your master identifies as 01 instead of 00 in my setup
so instead of 00 FE 10 02 80 8A E6 you have **01** FE 10 02 80 8A E7

Maybe changing that line to #define MASTER  0x01 could do the trick. Not sure if MASTER is used in all the commands or I jsut hardcoded 0x00 value (in such a case you can replace it by MASTER)
https://github.com/issalig/toshiba_air_cond/blob/3881bce2d6d0b48492f64b32a3a713a573effbe0/air/toshiba_serial.h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

issalig, 2025-01-19:
oooops, I have checked the code and it is always hardcoded, I should change it but in the meantime you can replace all the 0x00 by 0x01

For example power functions should be like this

void air_set_power_on(air_status_t *air) {
  byte data[] = {**REMOTE**, **MASTER**, 0x11, 0x03, 0x08, 0x41, 0x03, 0x18};
  air_send_data(air, data, sizeof(data));
}

void air_set_power_off(air_status_t *air)  {
  byte data[] = {**REMOTE**, **MASTER**, 0x11, 0x03, 0x08, 0x41, 0x02, 0x19};
  air_send_data(air, data, sizeof(data));
}

Gerhard1968, 2025-01-21:
only in toshiba_serial.h ?

issalig, 2025-01-21:
and the functions in toshiba_serial.hpp

air_set_power_on and the rest. byte 0 is normally source and byte 1 is destination
https://github.com/issalig/toshiba_air_cond/blob/3881bce2d6d0b48492f64b32a3a713a573effbe0/air/toshiba_serial.hpp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

Gerhard1968, 2025-01-22:
Sorry i am a hardware type an not software. I change 0x00 to 0x01 but now ich get allways an error:

- I change nothing in the Arduino IDE 2.3.2
- I use a new Wemos D1

In file included from c:\Users\HP EliteDesk\Documents\Arduino\libraries\ArduinoJson\src/ArduinoJson.hpp:42,
                 from c:\Users\HP EliteDesk\Documents\Arduino\libraries\ArduinoJson\src/ArduinoJson.h:9,
                 from C:\Users\HP EliteDesk\Documents\Arduino\toshiba_air_cond-master\air_copy_20250122164919\air_copy_20250122164919.ino:77:
c:\Users\HP EliteDesk\Documents\Arduino\libraries\ArduinoJson\src/ArduinoJson/Variant/ConverterImpl.hpp: In instantiation of 'static void ArduinoJson::V730PB22::Converter<T, Enable>::toJson(const T&, ArduinoJson::V730PB22::JsonVariant) [with T = char []; Enable = void]':
c:\Users\HP EliteDesk\Documents\Arduino\libraries\ArduinoJson\src/ArduinoJson/Variant/VariantRefBaseImpl.hpp:139:21:   required from 'bool ArduinoJson::V730PB22::detail::VariantRefBase<TDerived>::doSet(const T&, ArduinoJson::V730PB22::detail::false_type) const [with TConverter = ArduinoJson::V730PB22::Converter<char [], void>; T = char []; TDerived = ArduinoJson::V730PB22::detail::MemberProxy<ArduinoJson::V730PB22::JsonDocument&, ArduinoJson::V730PB22::detail::RamString>; ArduinoJson::V730PB22::detail::false_type = ArduinoJson::V730PB22::detail::integral_constant<bool, false>]'
c:\Users\HP EliteDesk\Documents\Arduino\libraries\ArduinoJson\src/ArduinoJson/Variant/VariantRefBase.hpp:298:29:   required from 'bool ArduinoJson::V730PB22::detail::VariantRefBase<TDerived>::doSet(const T&) const [with TConverter = ArduinoJson::V730PB22::Converter<char [], void>; T = char []; TDerived = ArduinoJson::V730PB22::detail::MemberProxy<ArduinoJson::V730PB22::JsonDocument&, ArduinoJson::V730PB22::detail::RamString>]'
c:\Users\HP EliteDesk\Documents\Arduino\libraries\ArduinoJson\src/ArduinoJson/Variant/VariantRefBase.hpp:82:46:   required from 'bool ArduinoJson::V730PB22::detail::VariantRefBase<TDerived>::set(const T&) const [with T = char []; TDerived = ArduinoJson::V730PB22::detail::MemberProxy<ArduinoJson::V730PB22::JsonDocument&, ArduinoJson::V730PB22::detail::RamString>]'
c:\Users\HP EliteDesk\Documents\Arduino\libraries\ArduinoJson\src/ArduinoJson/Object/MemberProxy.hpp:38:14:   required from 'ArduinoJson::V730PB22::detail::MemberProxy< <template-parameter-1-1>, <template-parameter-1-2> >& ArduinoJson::V730PB22::detail::MemberProxy< <template-parameter-1-1>, <template-parameter-1-2> >::operator=(const T&) [with T = char []; TUpstream = ArduinoJson::V730PB22::JsonDocument&; AdaptedString = ArduinoJson::V730PB22::detail::RamString]'
C:\Users\HP EliteDesk\Documents\Arduino\toshiba_air_cond-master\air_copy_20250122164919\process_request.hpp:155:24:   required from here
c:\Users\HP EliteDesk\Documents\Arduino\libraries\ArduinoJson\src/ArduinoJson/Variant/ConverterImpl.hpp:30:18: error: no matching function for call to 'convertToJson(const char [], ArduinoJson::V730PB22::JsonVariant&)'
   30 |     convertToJson(src, dst); // Error here? See https://arduinojson.org/v7/unsupported-set/
      |     ~~~~~~~~~~~~~^~~~~~~~~~
In file included from c:\Users\HP EliteDesk\Documents\Arduino\libraries\ArduinoJson\src/ArduinoJson.hpp:33,
                 from c:\Users\HP EliteDesk\Documents\Arduino\libraries\ArduinoJson\src/ArduinoJson.h:9,
                 from C:\Users\HP EliteDesk\Documents\Arduino\toshiba_air_cond-master\air_copy_20250122164919\air_copy_20250122164919.ino:77:
c:\Users\HP EliteDesk\Documents\Arduino\libraries\ArduinoJson\src/ArduinoJson/Document/JsonDocument.hpp:422:13: note: candidate: 'void ArduinoJson::V730PB22::convertToJson(const ArduinoJson::V730PB22::JsonDocument&, ArduinoJson::V730PB22::JsonVariant)'
  422 | inline void convertToJson(const JsonDocument& src, JsonVariant dst) {
      |             ^~~~~~~~~~~~~
c:\Users\HP EliteDesk\Documents\Arduino\libraries\ArduinoJson\src/ArduinoJson/Document/JsonDocument.hpp:422:47: note:   no known conversion for argument 1 from 'const char []' to 'const ArduinoJson::V730PB22::JsonDocument&'
  422 | inline void convertToJson(const JsonDocument& src, JsonVariant dst) {
      |                           ~~~~~~~~~~~~~~~~~~~~^~~
In file included from c:\Users\HP EliteDesk\Documents\Arduino\libraries\ArduinoJson\src/ArduinoJson.hpp:42,
                 from c:\Users\HP EliteDesk\Documents\Arduino\libraries\ArduinoJson\src/ArduinoJson.h:9,
                 from C:\Users\HP EliteDesk\Documents\Arduino\toshiba_air_cond-master\air_copy_20250122164919\air_copy_20250122164919.ino:77:
c:\Users\HP EliteDesk\Documents\Arduino\libraries\ArduinoJson\src/ArduinoJson/Variant/ConverterImpl.hpp:261:13: note: candidate: 'void ArduinoJson::V730PB22::convertToJson(const Printable&, ArduinoJson::V730PB22::JsonVariant)'
  261 | inline void convertToJson(const ::Printable& src, JsonVariant dst) {
      |             ^~~~~~~~~~~~~
c:\Users\HP EliteDesk\Documents\Arduino\libraries\ArduinoJson\src/ArduinoJson/Variant/ConverterImpl.hpp:261:46: note:   no known conversion for argument 1 from 'const char []' to 'const Printable&'
  261 | inline void convertToJson(const ::Printable& src, JsonVariant dst) {
      |                           ~~~~~~~~~~~~~~~~~~~^~~
c:\Users\HP EliteDesk\Documents\Arduino\libraries\ArduinoJson\src/ArduinoJson/Variant/ConverterImpl.hpp:191:56: note: candidate: 'template<class T> ArduinoJson::V730PB22::detail::enable_if_t<ArduinoJson::V730PB22::detail::IsString<TString>::value> ArduinoJson::V730PB22::convertToJson(const T&, ArduinoJson::V730PB22::JsonVariant)'
  191 | inline detail::enable_if_t<detail::IsString<T>::value> convertToJson(
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
issalig, 2025-01-23:
Looks like ArduinoJson is complaining.

Probably they have change something in the APIs
I am using ArduinoJson 6.21.3 and it seems you are using v7

Maybe downgrading it will work.

These are the versions I use (might update it some day :) )

Usando librería LittleFS con versión 0.1.0 en la carpeta: /home/issalig/.arduino15/packages/esp8266/hardware/esp8266/3.0.2/libraries/LittleFS
Usando librería ESP8266WiFi con versión 1.0 en la carpeta: /home/issalig/.arduino15/packages/esp8266/hardware/esp8266/3.0.2/libraries/ESP8266WiFi
Usando librería WiFiManager con versión 2.0.16-rc.2 en la carpeta: /home/issalig/Arduino/libraries/WiFiManager
Usando librería ESP8266WebServer con versión 1.0 en la carpeta: /home/issalig/.arduino15/packages/esp8266/hardware/esp8266/3.0.2/libraries/ESP8266WebServer
Usando librería DNSServer con versión 1.1.1 en la carpeta: /home/issalig/.arduino15/packages/esp8266/hardware/esp8266/3.0.2/libraries/DNSServer
Usando librería arduinoWebSockets con versión 2.3.6 en la carpeta: /home/issalig/Arduino/libraries/arduinoWebSockets
Usando librería ESPAsyncTCP con versión 1.2.2 en la carpeta: /home/issalig/Arduino/libraries/ESPAsyncTCP
Usando librería SPI con versión 1.0 en la carpeta: /home/issalig/.arduino15/packages/esp8266/hardware/esp8266/3.0.2/libraries/SPI
Usando librería Wire con versión 1.0 en la carpeta: /home/issalig/.arduino15/packages/esp8266/hardware/esp8266/3.0.2/libraries/Wire
Usando librería Adafruit_GFX_Library con versión 1.11.7 en la carpeta: /home/issalig/Arduino/libraries/Adafruit_GFX_Library
Usando librería Adafruit_BusIO con versión 1.11.6 en la carpeta: /home/issalig/Arduino/libraries/Adafruit_BusIO
Usando librería Adafruit_SSD1306 con versión 2.5.7 en la carpeta: /home/issalig/Arduino/libraries/Adafruit_SSD1306
Usando librería ArduinoOTA con versión 1.0 en la carpeta: /home/issalig/.arduino15/packages/esp8266/hardware/esp8266/3.0.2/libraries/ArduinoOTA
Usando librería ESP8266mDNS con versión 1.2 en la carpeta: /home/issalig/.arduino15/packages/esp8266/hardware/esp8266/3.0.2/libraries/ESP8266mDNS
Usando librería ArduinoJson con versión 6.21.3 en la carpeta: /home/issalig/Arduino/libraries/ArduinoJson
Usando librería NTPClient con versión 3.2.1 en la carpeta: /home/issalig/Arduino/libraries/NTPClient
Usando librería SoftwareSerial con versión 6.12.7 en la carpeta: /home/issalig/.arduino15/packages/esp8266/hardware/esp8266/3.0.2/libraries/SoftwareSerial
Usando librería Ticker con versión 1.0 en la carpeta: /home/issalig/.arduino15/packages/esp8266/hardware/esp8266/3.0.2/libraries/Ticker
Usando librería DHT_sensor_library con versión 1.4.4 en la carpeta: /home/issalig/Arduino/libraries/DHT_sensor_library
Usando librería Adafruit_BMP085_Library con versión 1.2.2 en la carpeta: /home/issalig/Arduino/libraries/Adafruit_BMP085_Library
Usando librería Hash con versión 1.0 en la carpeta: /home/issalig/.arduino15/packages/esp8266/hardware/esp8266/3.0.2/libraries/Hash
Usando librería Adafruit_Unified_Sensor con versión 1.1.9 en la carpeta: /home/issalig/Arduino/libraries/Adafruit_Unified_Sensor

Gerhard1968, 2025-01-25:
I downgrade ArduinoJson and the upload ok now, fine thank you.

I can switch now Fan/Dry/Cool/Head and Low/Med/High/Auto with the webinterface, but ON/OFF dosn´t work!
Mayby this line in toshiba_serial.h is the problem?

42   #define TIMER_HW_CANCEL     0x01

in the toshiba_serial.hpp i wrote

void air_set_power_on(air_status_t *air) {
byte data[] = {REMOTE, MASTER, 0x11, 0x03, 0x08, 0x41, 0x03, 0x18};
air_send_data(air, data, sizeof(data));
}

void air_set_power_off(air_status_t *air) {
byte data[] = {REMOTE, MASTER, 0x11, 0x03, 0x08, 0x41, 0x02, 0x19};
air_send_data(air, data, sizeof(data));
}

Here the log´s:

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

issalig, 2025-01-27:
Nice, there is some progress.

Regarding this line 42 #define TIMER_HW_CANCEL 0x01 , this is not the culprit, this just affect timer functions but that feature is not working well.

For power on you are sending 40 01 11 03 08 41 03 19   which looks ok to me.

Can you press power on/off on the "real" remote and check what is sent in the web (DEBUG CMD)?
Maybe we are missing sth.

Debug RAW is not really important (mainly to test the function that separate frames from byte stream). You can just use DEBUG CMD

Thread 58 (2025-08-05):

Optimistic behaviour when changing target temp from HA

makusets, 2025-08-05:
Thanks @issalig for this amazing piece of code. I love the new design and neat MQTT discovery.

I am not sure I have identified the issue correctly, and it might actually be a HA issue, but this is what I see happening.

When you change the target temp from the websocket, it seems that you first send the instruction and wait for confirmation, before actually updating what the display shows, This is a neat way of doing it, as often messages seem to get lost and you wouldn't know if the temp was really changed or not.  In the next cycle (30s?) the MQTT topic status temp is published and HA updates accordingly.

However, if I change the temp from HA, and the message gets lost, HA frontend behaves in an optimistic way and doesn't wind back the temperature. The sequence is as follows:
- I change the target temp in HA from 22 to 23, HA thermostat card immediately reflects this
- I can see the message gets published properly as a set temperature in MQTT
- Esp reads the MQTT set temp and send the instruction to the central unit, the websocket page still shows 22 as target temp
- The message gets lost, central unit doesn't acknowlegde? or whathever, the websocket remains the same at 22
- Next status temp from esp (every 30s?) to mqtt still sends 22 (nothing changed).
- HA doesn't doesn't update the displayed target temp in the frontend card, still shows 23 in an optimistic way. (wait over 10 min and still at 23)

I believe the issue might be the frontend card, because the topic gets published correctly and if I later change the target temp to something else through the websocket, it then gets updated in HA frontend.

Finally, if there is an acknowledge message from central unit when target temp is changed, then I think an immediate MQTT message to update HA would be a good idea, 30s seems a bit long. Same might apply to any setting changed I guess.

Any thoughts?

Thanks again.

issalig, 2025-08-05:
Hi @makusets,  thanks for the analysis.From my expierence it only takes some seconds (<30) to see the update in HA. Once the message is received by mqtt.cpp, statusChanged is true and then status message is sent to websockets in notifyWebsocketCLients()
I am checking the code and maybe it is better to do the notify (and update the air_status variable by calling air_parse_serial)  and then update it in HA. That way the update do not have to wait until the next cycle.
The code would be like this
In mqtt.cpp
 if (statusChanged) { print_log("[MQTT] command processed successfully\n"); notifyWebSocketClients(); // Update status update to websocket clients handleMQTT(); // Call handleMQTT to send updated status to HA }
In process_request.cpp
void notifyWebSocketClients() { String message; //update status air_parse_serial_data(&air_status); yield(); message = air_to_json(&air_status); webSocket.broadcastTXT(message); //reset serial buffers air_status.buffer_cmd = String(""); air_status.buffer_rx = String("");}
Also,  30 secs period may be too much. Lowering it to 10 secs could improve the responsiveness without affecting to the performance.
With these changes I think it should work. Tell me if that solves your problem.

From my side, I want to integrate telegram bot control but it interferes with the links2004/WebSockets library I use (only one SSL certificate is allowed and stoping /starting connections seem not work ok). I am considering to change to  ESPAsyncWebServer with AsyncWebSocket but I had problem some years ago in this project and that is why I chose links2004 library.
BR.

    En martes, 5 de agosto de 2025, 14:35:48 CEST, makusets ***@***.***> escribió:

 makusets created an issue (issalig/toshiba_air_cond#58)
Thanks @issalig for this amazing piece of code. I love the new design and neat MQTT discovery.

I am not sure I have identified the issue correctly, and it might actually be a HA issue, but this is what I see happening.

When you change the target temp from the websocket, it seems that you first send the instruction and wait for confirmation, before actually updating what the display shows, This is a neat way of doing it, as often messages seem to get lost and you wouldn't know if the temp was really changed or not. In the next cycle (30s?) the MQTT topic status temp is published and HA updates accordingly.

However, if I change the temp from HA, and the message gets lost, HA frontend behaves in an optimistic way and doesn't wind back the temperature. The sequence is as follows:

   - I change the target temp in HA from 22 to 23, HA thermostat card immediately reflects this
   - I can see the message gets published properly as a set temperature in MQTT
   - Esp reads the MQTT set temp and send the instruction to the central unit, the websocket page still shows 22 as target temp
   - The message gets lost, central unit doesn't acknowlegde? or whathever, the websocket remains the same at 22
   - Next status temp from esp (every 30s?) to mqtt still sends 22 (nothing changed).
   - HA doesn't doesn't update the displayed target temp in the frontend card, still shows 23 in an optimistic way. (wait over 10 min and still at 23)

I believe the issue might be the frontend card, because the topic gets published correctly and if I later change the target temp to something else through the websocket, it then gets updated in HA frontend.

Finally, if there is an acknowledge message from central unit when target temp is changed, then I think an immediate MQTT message to update HA would be a good idea, 30s seems a bit long. Same might apply to any setting changed I guess.

Any thoughts?

Thanks again.

—
Reply to this email directly, view it on GitHub, or unsubscribe.
You are receiving this because you were mentioned.Message ID: ***@***.***>

makusets, 2025-08-06:
Since you are only accessing the websocket from within your own wifi, you could use simple ws instead of wss and you will have a free ssl for telegram, am i right? Alternatively, as ESP8266 only handles 1 certificate, you could upgrade to esp32, that would work and would be a more stable board than the d1mini. I don't think starting/stopping would be a good approach, plus you might consume a lot of resources.

Regarding the above issue, the main issue was when updating from HA, but message not being received by the central unit. That's when HA doesn't roll back the dial. Am i right that you wait for an acknowledgement from central unit after a command is sent?

issalig, 2025-08-06:
No, I do not wait for an ack.
I just read the status messages from AC and update status variable which reported to web and mqtt.

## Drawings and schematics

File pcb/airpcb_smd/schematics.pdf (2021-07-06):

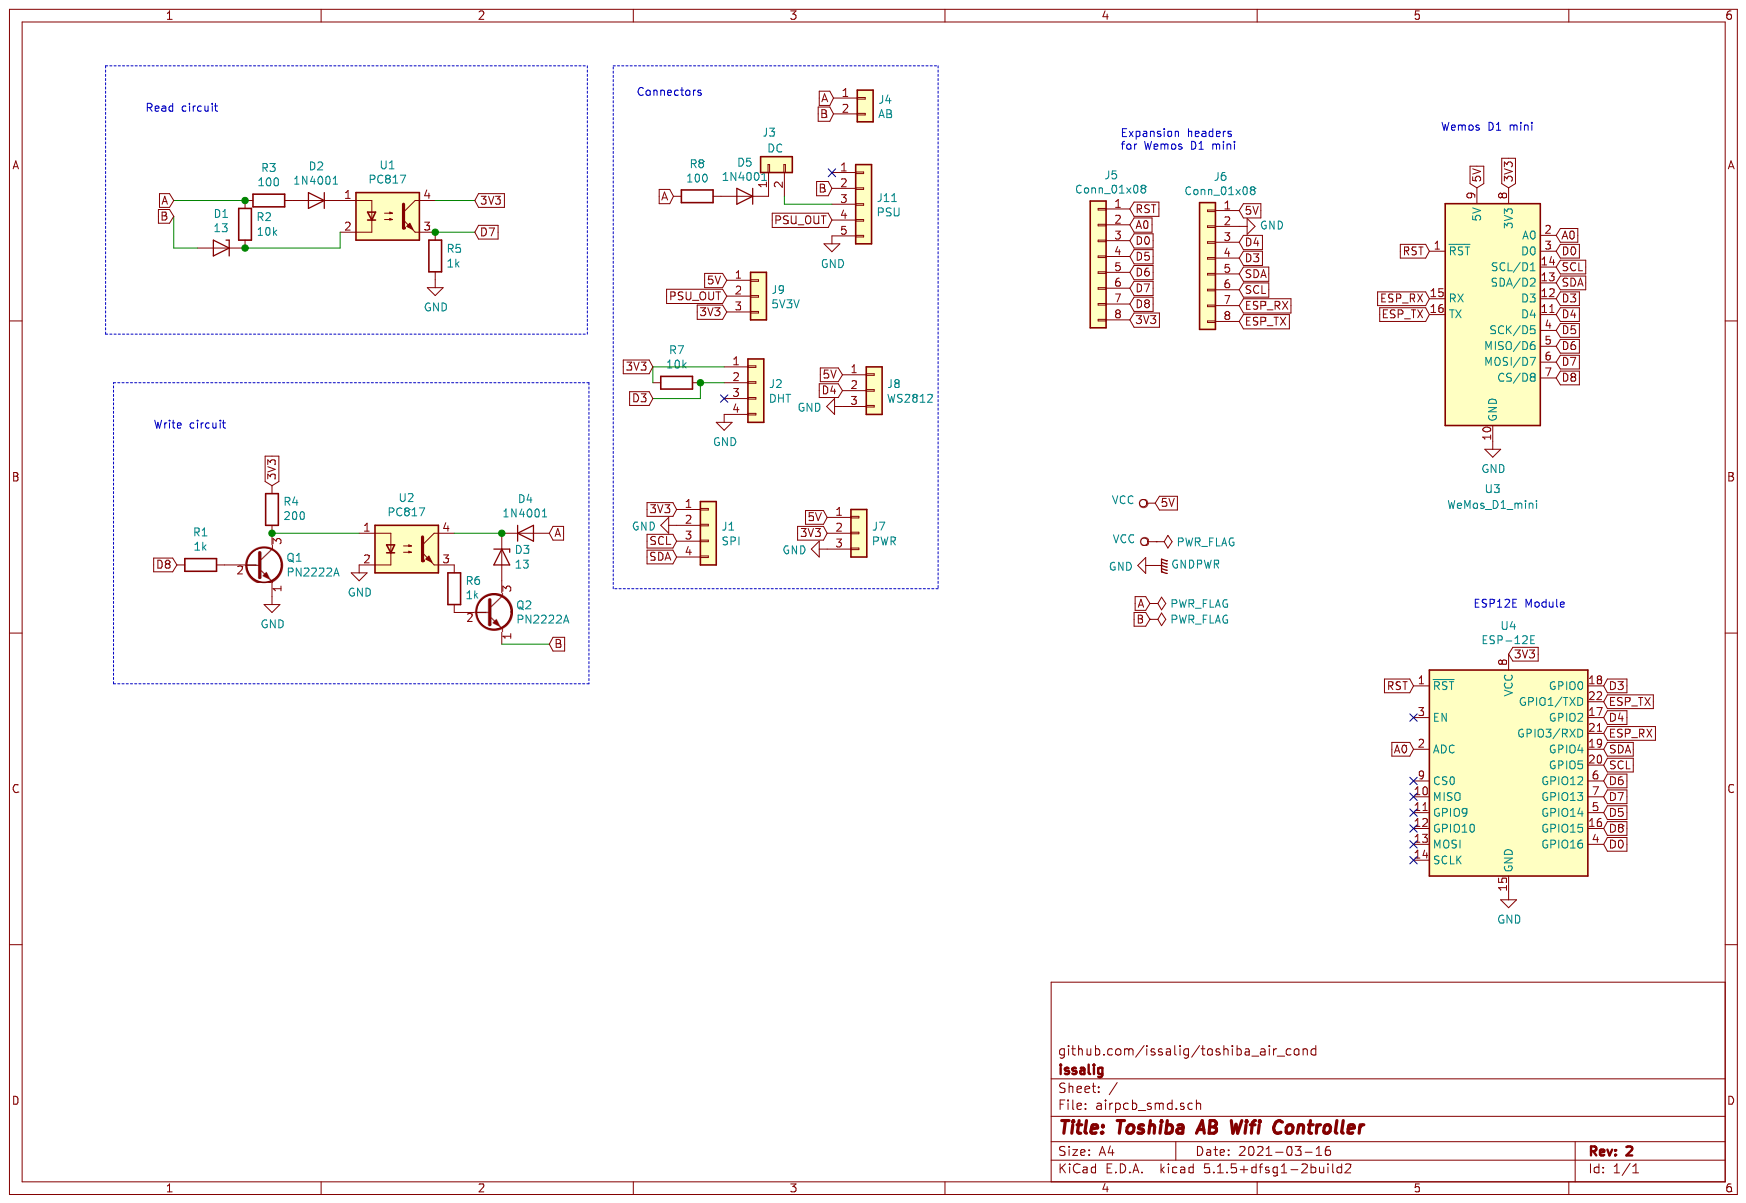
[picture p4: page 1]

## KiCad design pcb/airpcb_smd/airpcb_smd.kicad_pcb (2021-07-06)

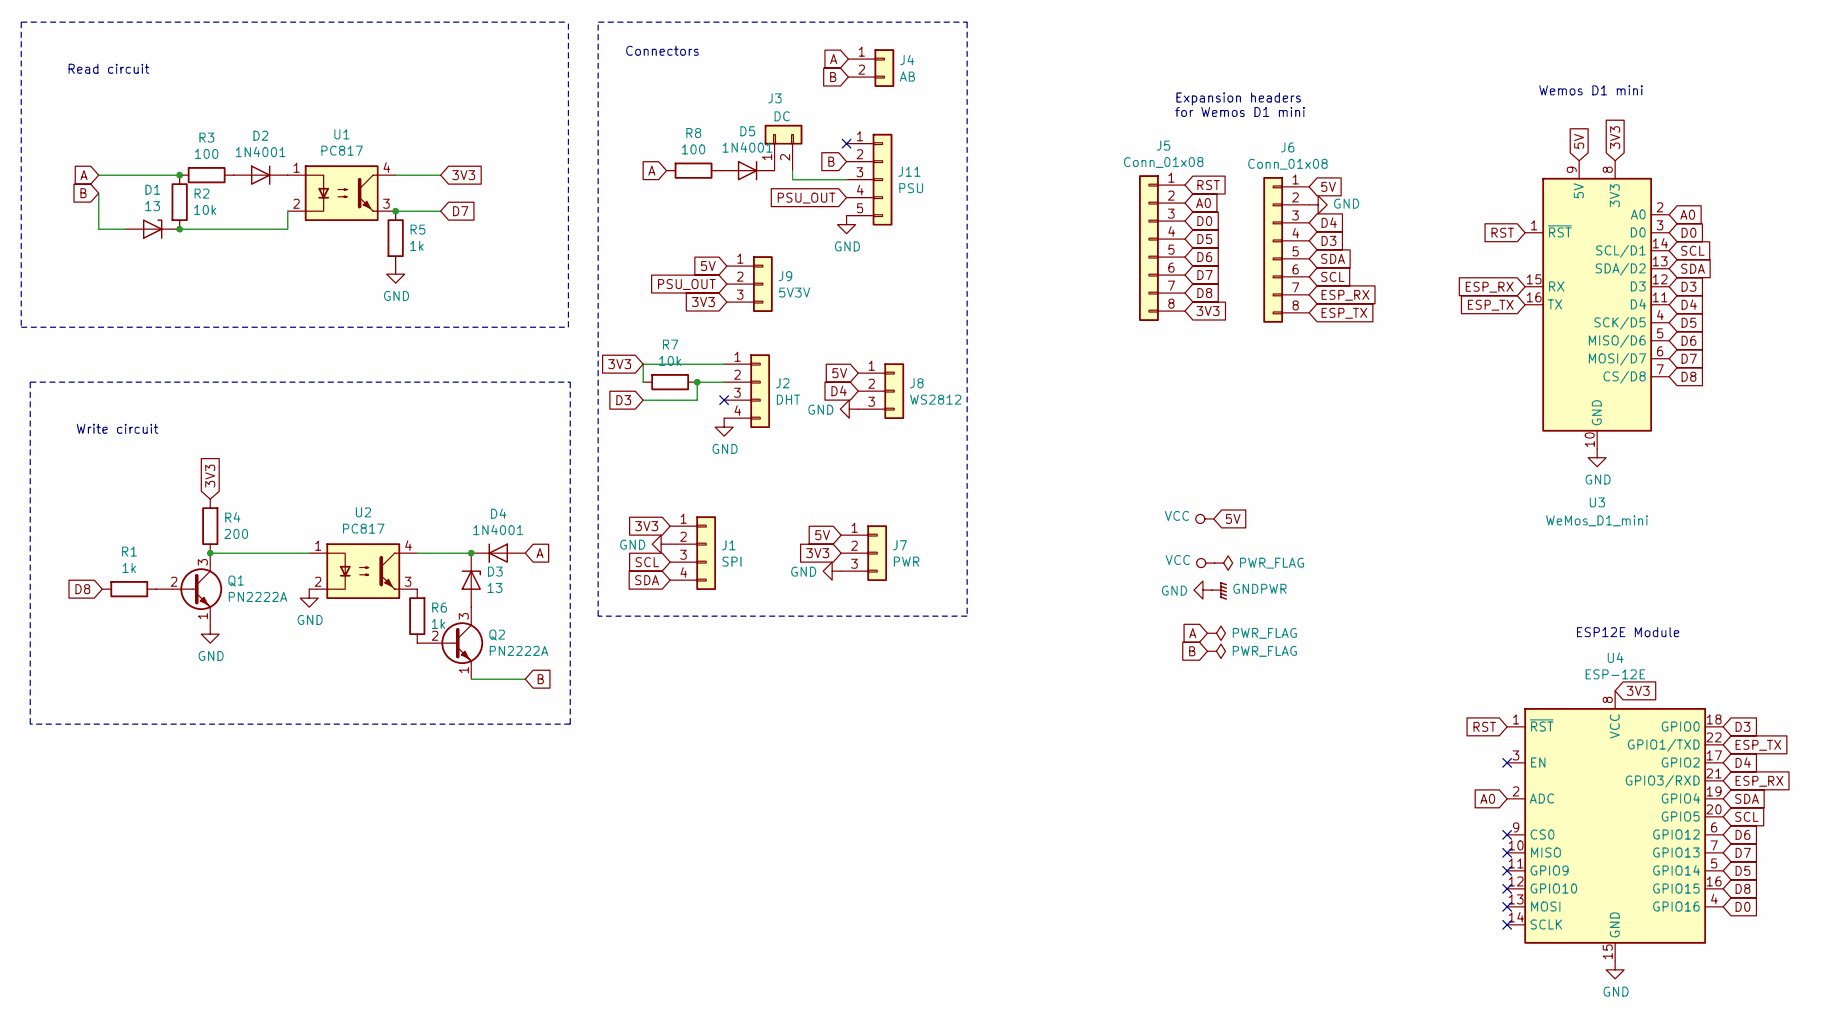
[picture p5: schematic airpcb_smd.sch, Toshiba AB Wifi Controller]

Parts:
D1, D3: 13; D_MiniMELF_Handsoldering
D2, D4, D5: 1N4001; D_SMA
J1: SPI; PinSocket_1x04_P2.54mm_Vertical
J2: DHT; PinSocket_1x04_P2.54mm_Vertical
J3: DC; PinSocket_1x02_P2.54mm_Vertical
J4: AB; PinSocket_1x02_P2.54mm_Vertical
J5, J6: Conn_01x08; PinSocket_1x08_P2.54mm_Vertical
J7: PWR; PinSocket_1x03_P2.54mm_Vertical
J8: WS2812; PinSocket_1x03_P2.54mm_Vertical
J9: 5V3V; PinSocket_1x03_P2.54mm_Vertical
J11: PSU; HW-108
Q1, Q2: PN2222A; SOT-23_Reverse_Handsoldering
R1, R5, R6: 1k; R_0805_2012Metric
R2, R7: 10k; R_0805_2012Metric
R3, R8: 100; R_0805_2012Metric
R4: 200; R_0805_2012Metric
U1, U2: PC817; DIP-4_W7.62mm
U3: WeMos_D1_mini; WEMOS_D1_mini_light
U4: ESP-12E

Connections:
3V3: J1.1, J2.1, J5.8, J7.2, J9.3, R4.2, R7.2, U1.4, U3.8 (3V3), U4.8 (VCC)
5V: J6.1, J7.1, J8.1, J9.1, U3.9 (5V)
A: D4.2 (A), J4.1, R2.1, R3.2, R8.2
A0: J5.2, U3.2 (A0), U4.2 (ADC)
B: D1.2 (A), J4.2, J11.2, Q2.1 (E)
D0: J5.3, U3.3 (D0), U4.4 (GPIO16)
D3: J2.2, J6.4, R7.1, U3.12 (D3), U4.18 (GPIO0)
D4: J6.3, J8.2, U3.11 (D4), U4.17 (GPIO2)
D5: J5.4, U3.4 (SCK/D5), U4.5 (GPIO14)
D6: J5.5, U3.5 (MISO/D6), U4.6 (GPIO12)
D7: J5.6, R5.1, U1.3, U3.6 (MOSI/D7), U4.7 (GPIO13)
D8: J5.7, R1.2, U3.7 (CS/D8), U4.16 (GPIO15)
ESP_RX: J6.7, U3.15 (RX), U4.21 (GPIO3/RXD)
ESP_TX: J6.8, U3.16 (TX), U4.22 (GPIO1/TXD)
GND: J1.2, J2.4, J6.2, J7.3, J8.3, J11.5, Q1.1 (E), R5.2, U2.2, U3.10 (GND), U4.15 (GND)
unnamed: D1.1 (K), R2.2, U1.2
unnamed: D2.1 (K), U1.1
unnamed: D2.2 (A), R3.1
unnamed: D3.1 (K), D4.1 (K), U2.4
unnamed: D3.2 (A), Q2.3 (C)
unnamed: D5.1 (K), J3.1
unnamed: D5.2 (A), R8.1
unnamed: J3.2, J11.3
unnamed: Q1.2 (B), R1.1
unnamed: Q1.3 (C), R4.1, U2.1
unnamed: Q2.2 (B), R6.1
unnamed: R6.2, U2.3
PSU_OUT: J9.2, J11.4
RST: J5.1, U3.1 (~RST), U4.1 (~RST)
SCL: J1.3, J6.6, U3.14 (SCL/D1), U4.20 (GPIO5)
SDA: J1.4, J6.5, U3.13 (SDA/D2), U4.19 (GPIO4)

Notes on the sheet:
Read circuit
Write circuit
Connectors
ESP12E Module
Wemos D1 mini
Expansion headers for Wemos D1 mini

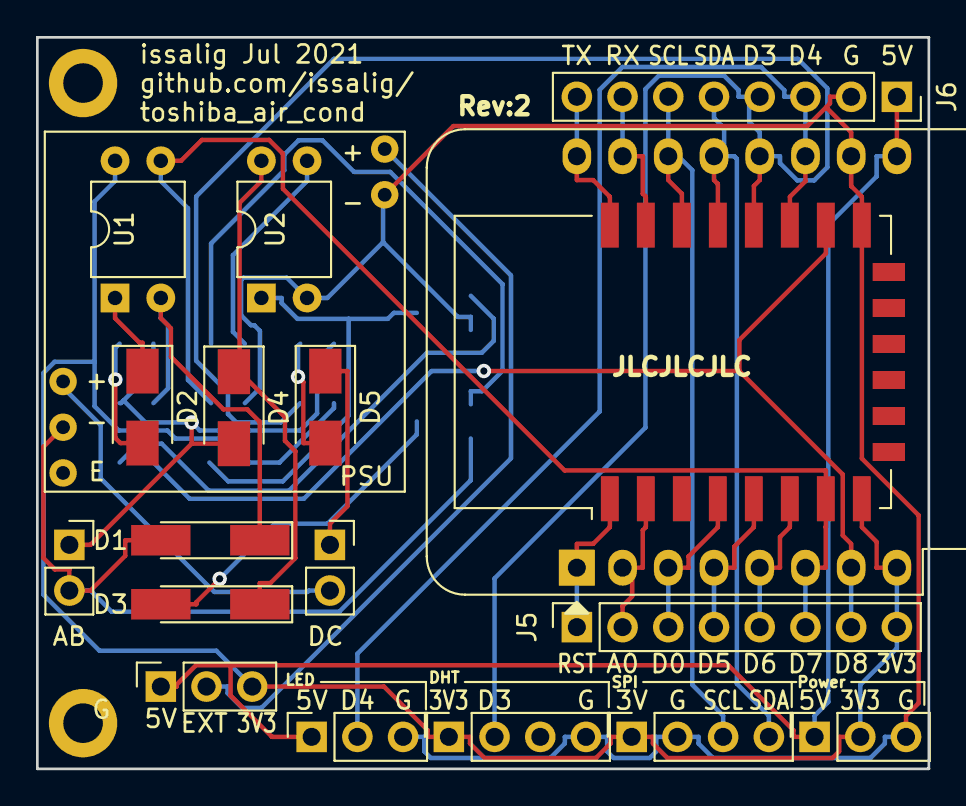
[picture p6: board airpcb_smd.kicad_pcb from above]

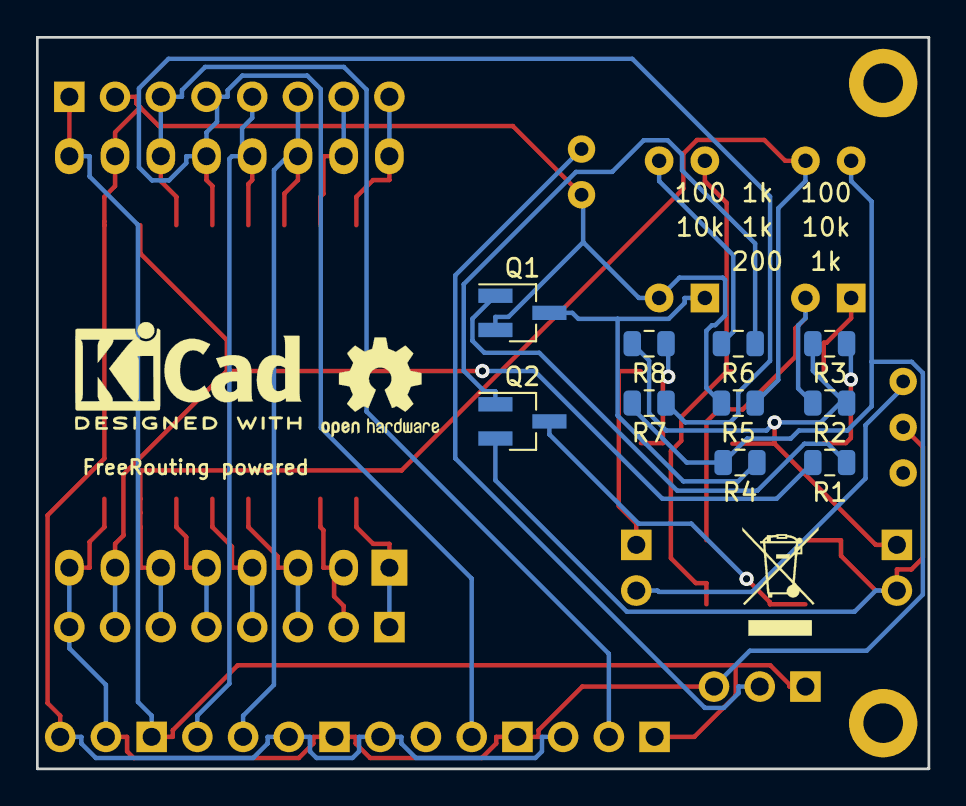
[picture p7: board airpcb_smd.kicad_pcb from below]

Board: 2 copper layers, 49.5 x 40.6 mm, 34 parts (13 on the bottom side), 31 nets.

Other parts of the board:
L1: KiCad-Logo2_5mm_SilkScreen
L2: OSHW-Logo2_7.3x6mm_SilkScreen
L3: WEEE-Logo_4.2x6mm_SilkScreen
M1, M2: MountingHole_2.2mm_M2_DIN965_Pad

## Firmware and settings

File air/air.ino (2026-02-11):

/*
  Name:         air.ino
  Description:  Controls toshiba air conditioner
  Author:       issalig

  History:      01/06/2020 initial version
                24/07/2025 v2.0 superloaded with MQTT, OLED and a lots of goodies
                2026 remote announce, dn codes, pin configuration, serial output debug and more

  Instructions:
                HW
                R/W circuit (see readme.md)
                Oled screen connected to D1 (SCL) D2 (SDA) (optional)
                AHT20 + BMP280 connected to D1 (SCL) D2 (SDA) (optional but one temperature sensor is needed if autonomous mode is used)

                Software serial rx on D7, tx on D8
                Wemos mini D1

                SW
                The recommended editor is VSCode with PlatformIO, but you can use Arduino IDE too.
                Upload data directory with ESP8266SketchDataUpload and flash it with USB for the first time. Then, when installed you can use OTA updates.                
                If you want to use MQTT, set the MQTT_HOST, MQTT_PORT, MQTT_USER and MQTT_PASSWORD
                Web server is available at http://air.local and OTA password is set in config.h

  References:   https://github.com/tttapa/ESP8266/
                https://github.com/luisllamasbinaburo/ESP8266-Examples
                https://diyprojects.io/esp8266-web-server-part-5-add-google-charts-gauges-and-charts/#.X0gBsIbtY5k

  Dependencies:
            |-- EspSoftwareSerial @ 8.2.0
            |-- Adafruit SSD1306 @ 2.5.14
            |-- Adafruit GFX Library @ 1.12.1
            |-- WiFiManager @ 2.0.17
            |-- ESP8266WiFi @ 1.0
            |-- WebSockets @ 2.7.3
            |-- ArduinoJson @ 7.4.2
            |-- LittleFS @ 0.1.0
            |-- PubSubClient @ 2.8.0
            |-- NTPClient @ 3.2.1
            |-- Adafruit Unified Sensor @ 1.1.15
            |-- Adafruit AHTX0 @ 2.0.5
            |-- Adafruit BMP280 Library @ 3.0.0
            |-- Adafruit BME280 Library @ 2.3.0
            |-- ArduinoOTA @ 1.0
            |-- ESP8266WebServer @ 1.0
            |-- ESP8266mDNS @ 1.2
            |-- Ticker @ 1.0
            |-- Wire @ 1.0

  This code in under license GPL v2

  GNU GENERAL PUBLIC LICENSE

  Version 2, June 1991

  Copyright (C) 1989, 1991 Free Software Foundation, Inc.
  51 Franklin Street, Fifth Floor, Boston, MA  02110-1301, USA

  Everyone is permitted to copy and distribute verbatim copies
  of this license document, but changing it is not allowed.
*/

#include "config.h" // check it for compilation time settings
#include "settings.h" // check it for persistent settings structure
#include "file_manager_html.h" //unified file manager
#include "display.h"
#include "sensors.h"

#include "LittleFS.h"
#include <ESP8266WiFi.h>

#ifdef USE_ASYNC // AsyncWebServer
#include <WiFiManager.h>
#include <ESPAsyncTCP.h>
#include <ESPAsyncWebServer.h>
#else //use links2004 websocketserver
#include <WiFiManager.h>
#include <ESP8266WebServer.h>
#include <WebSocketsServer.h> //https://github.com/Links2004/arduinoWebSockets/
#endif

// SPI.h removed - not used and causes conflicts with I2C on GPIO14
//#include <SPI.h>

#include <Adafruit_Sensor.h>

#ifdef USE_OTA
#include <ArduinoOTA.h>
#endif

#include <ESP8266mDNS.h>
#include <FS.h>
#include <ArduinoJson.h>  //by Benoit Blanchon
#include <NTPClient.h>    //https://github.com/arduino-libraries/NTPClient
#include <WiFiUdp.h>
#include "ac_protocol.h"
//#include "MySimpleTimer.hpp"
#include "my_timer.h"
#include "process_request.h"
#include "print_log.h"  // print log functions
#ifdef USE_TELEGRAM
#include "telegram_bot.h" // Telegram bot functions
#endif

#ifdef USE_MQTT
#include "mqtt.h"
extern bool getMQTTStatus();
#endif 

//for LED status
#include <Ticker.h>
Ticker ticker;

#ifndef LED_BUILTIN
#define LED_BUILTIN 13 // ESP32 DOES NOT DEFINE LED_BUILTIN
#endif

int LED = LED_BUILTIN;

//not necessary because now we use WifiManager
//change it according to your network
IPAddress ip(192, 168, 2, 200);
IPAddress gateway(192, 168, 2, 1);
IPAddress subnet(255, 255, 255, 0);
IPAddress dns(8, 8, 8, 8);

air_status_t air_status;
my_timer timerOnOff;

#ifdef USE_ASYNC
AsyncWebServer server(80);
AsyncWebSocket webSocket("/ws");
#else
ESP8266WebServer server(80);       // create a web server on port 80
WebSocketsServer webSocket(81);    // create a websocket server on port 81
#endif

File fsUploadFile;                 // a File variable to temporarily store the received file


#ifdef USE_AHT20
#include <Adafruit_AHTX0.h>
Adafruit_AHTX0 aht;
#endif

#ifdef USE_BMP280
#include <Adafruit_BMP280.h>
Adafruit_BMP280 bmp280;
#endif

#ifdef USE_BME280
#include <Adafruit_BME280.h>
Adafruit_BME280 bme280;
#endif

#ifdef USE_AHT20
float aht_t_current = -999.0;
bool humidity_status = false;
#endif

#ifdef USE_BMP280
float bmp280_t_current = -999.0;
bool pressure_status = false;
#endif

#ifdef USE_BME280
float bme280_t_current = -999.0;
bool bme280_pressure_status = false;
bool bme280_humidity_status = false;
#endif


// Arrays for storing sensor data
float ac_sensor_temperature[MAX_LOG_DATA];
int ac_outdoor_te[MAX_LOG_DATA];
float sensor_temperature[MAX_LOG_DATA]; // Centralized temperature from best available sensor
float sensor_humidity[MAX_LOG_DATA];    // Centralized humidity (available regardless of sensor type)
float sensor_pressure[MAX_LOG_DATA];    // Centralized pressure
unsigned long timestamps[MAX_LOG_DATA]; // Timestamps for sensor readings
int temp_idx = 0; // Index for circular temperature arrays

// Current readings (for real-time data)
float sensor_temperature_current = -999.0;  // Current temperature from best sensor
float sensor_humidity_current = -999.0;     // Current humidity from best sensor
float sensor_pressure_current = -999.0;     // Current pressure from best sensor


// sensors ids
byte sensor_ids[] = {
  INDOOR_ROOM,
  INDOOR_FAN_SPEED,
  INDOOR_TA, INDOOR_TCJ, INDOOR_TC,
  INDOOR_FILTER_TIME,
  INDOOR_FAN_RUN_TIME,
  OUTDOOR_TE, OUTDOOR_TO,
  OUTDOOR_TD, OUTDOOR_TS, OUTDOOR_THS,
  OUTDOOR_CURRENT,
  OUTDOOR_HOURS, 
  OUTDOOR_TL, 
  OUTDOOR_COMP_FREQ,
  OUTDOOR_LOWER_FAN_SPEED, 
  OUTDOOR_UPPER_FAN_SPEED
};

// Define NTP Client to get time
WiFiUDP ntpUDP;
const long utcOffsetInSeconds = 3600; //1 hour for Europe/Brussels
int timeOffset = 0;
NTPClient timeClient(ntpUDP, "europe.pool.ntp.org", 0); //do not apply utc here

// Timers
my_timer timerTemperature;
my_timer timerStatus;
my_timer timerReadSerial;
my_timer timerSaveFile;
my_timer timerMQTT; 
my_timer timerAutonomous;

//MySimpleTimer timerTelegram;

bool autonomous_mode = false; // use autonomous mode if there is no wired remote
bool simulation_mode = false; // Set to true to enable simulation mode without AC unit
bool listen_mode = false; // listen mode to just read serial data

int temperature_interval = 1800;//1800; //in secs, 30 mins for temperature readings

//bool mqtt_enabled = true;



/*__________________________________________________________SETUP__________________________________________________________*/

void setup() {

  my_timer_init(&timerOnOff);
  my_timer_init(&timerTemperature);
  my_timer_init(&timerStatus);
  my_timer_init(&timerReadSerial);
  my_timer_init(&timerSaveFile);
  my_timer_init(&timerMQTT);
  my_timer_init(&timerAutonomous);
  #ifdef USE_TELEGRAM
  my_timer_init(&timerTelegram);
  #endif

  Serial.begin(9600);        // Start the Serial communication to send messages to the computer
  delay(10);
  print_log("Air conditioning starts!");

  startWifiManager();          // Use wifimanager to connect
  //is_reset_button();
  #ifdef USE_OTA
  startOTA();                  // Start the OTA service
  #endif

  startLittleFS();             // Start the LittleFS and list all contents
  startSettings();             // Load and apply settings

  startWebSocket();            // Start a WebSocket server
  startMDNS();                 // Start the mDNS responder
  startServer();               // Start a HTTP server with a file read handler and an upload handler

  // Run I2C scanner during startup to diagnose sensor issues
  print_logf("[STARTUP] I2C Configuration: SDA=GPIO%d, SCL=GPIO%d\n", air_status.sda_pin, air_status.scl_pin);
  i2c_scanner();

  init_air_serial(&air_status);// Start air conditioning structure and software serial
  air_status.ip = WiFi.localIP().toString();

  startReadSerial();           // Start timer for serial readings (1s)
  startStatus();               // Start timer for status print (10s)
  startTime();                 // Get time from NTP server
  startTemperature();          // Start timer for temperature readings (120s)

  #ifdef USE_SCREEN
  startDisplay();
  #endif  

  // Show IP address on display after WiFi is connected
  #ifdef USE_SCREEN
  showIPDisplay();
  #endif

  #ifdef USE_MQTT
  if (WiFi.status() == WL_CONNECTED) {
    loadMQTTConfigFromFile();
    startMQTT();
    startMQTTTimer();
  } else {
    print_log("[MQTT] WiFi not connected");
  }
  #endif //USE_MQTT

  #ifdef USE_TELEGRAM
    startTelegram();
  #endif

  if (simulation_mode) {
    initSimulationMode();
  }

  // Serial.println();
  // Serial.println("=== ESP8266 Flash Info ===");
  // Serial.printf("Flash Chip ID: %08X\n", ESP.getFlashChipId());
  // Serial.printf("Flash Size: %u bytes (%.1f MB)\n", ESP.getFlashChipRealSize(), ESP.getFlashChipRealSize() / 1024.0 / 1024.0);
  // Serial.printf("Sketch Size: %u bytes\n", ESP.getSketchSize());
  // Serial.printf("Free Sketch Space: %u bytes\n", ESP.getFreeSketchSpace());
  // Serial.printf("Filesystem Size: %u bytes\n", ESP.getFlashChipSize() - ESP.getSketchSize());

}

// start functions

void startTime() {
  long int boot_time;

  timeClient.begin();                        // Get NTP time
  //timeClient.update();
  for (int i = 0; i < 5; i++) {
    timeClient.update();                     // update time
    boot_time = timeClient.getEpochTime();
    if (boot_time > 3600) break;             // check we are not still in 1970
  }
  air_status.boot_time = boot_time;
}

void startSettings() {
  // Try to load settings
  settings_t saved_settings;
  if (loadSettings(&air_status, &saved_settings)) {
    print_log("[SETTINGS] Applying saved settings");
    applySettings(&air_status, &saved_settings);   
  } else {
    // Set default I2C pins if no settings file exists
    air_status.sda_pin = 4;  // Default SDA D2 (GPIO4)
    air_status.scl_pin = 5;  // Default SCL D1 (GPIO5)
    print_logf("[SETTINGS] No settings found, using defaults SDA %d SCL %d", air_status.sda_pin, air_status.scl_pin);
    Wire.begin(air_status.sda_pin, air_status.scl_pin);

    // set serial pins
    air_status.txpin = 15; // TX D8 (GPIO15)
    air_status.rxpin = 13; // RX D7 (GPIO13)
  }
}

void startTemperature() {
  my_timer_set_unit(&timerTemperature, 1000); // 1000ms
  my_timer_set_interval(&timerTemperature, temperature_interval); //update every XX s
  my_timer_repeat(&timerTemperature);
  my_timer_start(&timerTemperature); 

  // Clear centralized arrays
  memset(ac_sensor_temperature, 0, MAX_LOG_DATA * sizeof(float));
  memset(ac_outdoor_te, 0, MAX_LOG_DATA * sizeof(int));
  memset(sensor_temperature, 0, MAX_LOG_DATA * sizeof(float));
  memset(sensor_humidity, 0, MAX_LOG_DATA * sizeof(float));
  memset(sensor_pressure, 0, MAX_LOG_DATA * sizeof(float));
  memset(timestamps, 0, MAX_LOG_DATA * sizeof(unsigned long));

  // Initialize sensors
  initAHT20Sensor();
  initBMP280Sensor();
  initBME280Sensor();

  // Get initial sensor readings
  env_snapshot snapshot = readEnvironmentalSensors("INIT");

  // Set centralized readings with AC fallback for temperature
  sensor_temperature[0] = snapshot.temp_valid ? snapshot.temp : air_status.remote_sensor_temp;
  sensor_humidity[0] = snapshot.humidity_valid ? snapshot.humidity : -999.0;
  sensor_pressure[0] = snapshot.pressure_valid ? snapshot.pressure : -999.0;

  sensor_temperature_current = sensor_temperature[0];
  sensor_humidity_current = sensor_humidity[0];
  sensor_pressure_current = sensor_pressure[0];

  print_logf("[SENSOR] Temperature source: %s (%.1f°C)", 
             snapshot.temp_valid ? snapshot.temp_source.c_str() : "AC fallback", 
             sensor_temperature[0]);
  
  if (snapshot.humidity_valid) {
    print_logf("[SENSOR] Humidity source: %s (%.1f%%)", snapshot.humidity_source.c_str(), sensor_humidity[0]);
  }
  
  if (snapshot.pressure_valid) {
    print_logf("[SENSOR] Pressure source: %s (%.1f hPa)", snapshot.pressure_source.c_str(), sensor_pressure[0]);
  }

  // Query AC and log first sample
  air_send_ping(&air_status);
  air_parse_serial(&air_status);
  ac_sensor_temperature[0] = air_status.remote_sensor_temp;

  air_query_sensor(&air_status, OUTDOOR_TE);
  air_parse_serial(&air_status);
  ac_outdoor_te[0] = air_status.outdoor_te;

  timeClient.update();
  timestamps[0] = timeClient.getEpochTime();

  temp_idx = (temp_idx + 1) % MAX_LOG_DATA;
}

void startStatus() {
  my_timer_set_unit(&timerStatus, 1000); // 1000ms
  my_timer_set_interval(&timerStatus, 150); //update every XX s
  my_timer_repeat(&timerStatus);
  my_timer_start(&timerStatus);

  air_query_sensors(&air_status, sensor_ids, sizeof(sensor_ids)); //query sensors on start

  request_master_info(&air_status); //request master info on start
}
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
void loop() {
  if (listen_mode) {
    // LISTEN MODE - Only essential operations to avoid missing serial data
    handleReadSerial();      // Priority: Read serial as often as possible
    
    #ifdef USE_ASYNC
    // AsyncWebSocket is handled automatically by the server
    #else
    webSocket.loop();        // Handle websocket for control/monitoring
    #endif
    
    server.handleClient();   // Handle web requests (minimal overhead)
    
    #ifdef USE_OTA
    ArduinoOTA.handle();     // Keep OTA available for updates
    #endif
    
    yield();                 // Allow WiFi stack to function
    
  } else {

  // NORMAL MODE - Full functionality

  handleTimerOnOff();//yield(); //now yield is done inside the handlers
  handleTemperature();//yield();
  handleStatus();//yield();
  handleReadSerial();//yield();
  #ifdef USE_MQTT
  handleMQTT();//yield();
  #endif

  #ifdef USE_ASYNC
  // AsyncWebSocket is handled automatically by the server
  #else
  webSocket.loop();//yield();
  #endif

  server.handleClient();//yield();
  #ifdef USE_OTA
  ArduinoOTA.handle();//yield();
  #endif

  MDNS.update(); yield();
  
  #ifdef USE_SCREEN
  showDisplay();//yield();
  #endif
  
  handleSaveFile();yield();
  handleAutonomousMode();//yield();
  
  #ifdef USE_TELEGRAM
  handleTelegramMessages();//yield();
  #endif
  }
}

/*__________________________________________________________START_FUNCTIONS__________________________________________________________*/

void startWiFi() { //fixed IP
  WiFi.mode(WIFI_STA);
  WiFi.config(ip, gateway, subnet, dns);
  WiFi.begin(w_ssid, w_passwd);
  Serial.print("Connected to:\t");
  Serial.println(w_ssid);

  // wait for connection
  while (WiFi.status() != WL_CONNECTED)
  {
    delay(200);
    Serial.print('.');
  }

  // show IP
  Serial.println("[WIFI] Connection stablished.");
  Serial.print("[WIFI] IP address:\t");
  Serial.println(WiFi.localIP());
}

#ifdef USE_OTA
void startOTA() { // Start the OTA service
  ArduinoOTA.setHostname(OTAName);
  ArduinoOTA.setPassword(OTAPassword);

  ArduinoOTA.onStart([]() {
    Serial.println("[OTA] Start");
  });
  ArduinoOTA.onEnd([]() {
    Serial.println("\r\n[OTA] End");
  });
  ArduinoOTA.onProgress([](unsigned int progress, unsigned int total) {
    Serial.printf("Progress: %u%%\r", (progress / (total / 100)));
  });
  ArduinoOTA.onError([](ota_error_t error) {
    Serial.printf("Error[%u]: ", error);
    if (error == OTA_AUTH_ERROR) Serial.println("Auth Failed");
    else if (error == OTA_BEGIN_ERROR) Serial.println("Begin Failed");
    else if (error == OTA_CONNECT_ERROR) Serial.println("Connect Failed");
    else if (error == OTA_RECEIVE_ERROR) Serial.println("Receive Failed");
    else if (error == OTA_END_ERROR) Serial.println("End Failed");
  });
  ArduinoOTA.begin();
  Serial.println("[OTA] Ready");
}
#endif

void startLittleFS() { // Start the LittleFS and list all contents
  LittleFS.begin();                             // Start the SPI Flash File System (LittleFS)
  Serial.println("[LITTLEFS] Started. Contents:");
  {
    Dir dir = LittleFS.openDir("/");
    while (dir.next()) {                      // List the file system contents
      String fileName = dir.fileName();
      size_t fileSize = dir.fileSize();
      Serial.printf("\tFS File: %s, size: %s\r\n", fileName.c_str(), formatBytes(fileSize).c_str());
    }
    Serial.printf("\n");
  }
}

void startWebSocket() { // Start a WebSocket server
#ifdef USE_ASYNC
  webSocket.onEvent(onWsAsyncEvent);
  server.addHandler(&webSocket);
  Serial.println("AsyncWebSocket server started.");
#else //use links2004
  webSocket.begin();                          // start the websocket server
  webSocket.onEvent(onWsEvent);          // if there's an incomming websocket message, go to function 'webSocketEvent'
  webSocket.enableHeartbeat(3000, 2000, 2); // short time (3000) to allow fast reception
  Serial.println("[WEBSOCKET] Server started.");
#endif
}

void stopWebSocket() {
#ifdef USE_ASYNC
  webSocket.closeAll();  // Close all client connections
  Serial.println("AsyncWebSocket handler removed.");
#else
  // For links2004 WebSocket server
  webSocket.disconnect();  // Disconnect all clients
  webSocket.close();       // Close the WebSocket server
  Serial.println("[WEBSOCKET] Server stopped.");
#endif
}

void startMDNS() { // Start the mDNS responder
  MDNS.begin(mdnsName);                        // start the multicast domain name server
  Serial.print("[MDNS] Responder started: http://");
  Serial.print(mdnsName);
  Serial.println(".local");
}

void startServer() { // Start a HTTP server with a file read handler and an upload handler
#ifdef USE_ASYNC
  Serial.print("Using Async");

  server.onNotFound(handleNotFound);          // if someone requests any other file or page, go to function 'handleNotFound'
  // and check if the file exists

#else
  server.on("/edit.html",  HTTP_POST, []() {  // If a POST request is sent to the /edit.html address,
    server.send(200, "text/plain", "");
  }, handleFileUpload);                       // go to 'handleFileUpload'

  // Serve built-in file manager (replaces separate upload and delete pages)
  server.on("/upload", HTTP_GET, []() {
        server.send_P(200, "text/html", file_manager_html);
  });

  server.on("/upload", HTTP_POST, []() {  
    // Response handled by handleFileUpload which sends a 303 Redirect
  }, handleFileUpload);                       

  // Built-in file manager (same as upload for unified interface)
  server.on("/delete", HTTP_GET, []() {
    server.send_P(200, "text/html", file_manager_html);
  });

  // File manager endpoint (same as upload for unified interface)
  server.on("/filemanager", HTTP_GET, []() {
    server.send_P(200, "text/html", file_manager_html);
  });

  // API endpoint to list files
  server.on("/api/files", HTTP_GET, []() {
    JsonDocument doc;
    JsonArray files = doc["files"].to<JsonArray>();
    
    Dir dir = LittleFS.openDir("/");
    while (dir.next()) {
      JsonObject file = files.add<JsonObject>();
      file["name"] = dir.fileName();
      file["size"] = dir.fileSize();
    }
    
    String response;
    serializeJson(doc, response);
    server.send(200, "application/json", response);
  });

  // API endpoint to delete files
  server.on("/api/delete", HTTP_POST, []() {
    String body = server.arg("plain");
    JsonDocument doc;
    DeserializationError error = deserializeJson(doc, body);
    
    if (!error && doc["filename"].is<const char*>()) {
      String filename = doc["filename"];
      
      // Add leading slash if not present
      if (!filename.startsWith("/")) {
        filename = "/" + filename;
      }
      
      
      if (LittleFS.exists(filename)) {
        if (LittleFS.remove(filename)) {
          print_logf("[DELETE] File deleted: %s", filename.c_str());
          server.send(200, "application/json", "{\"success\":true}");
        } else {
          server.send(200, "application/json", "{\"success\":false,\"error\":\"Failed to delete file\"}");
        }
      } else {
        server.send(200, "application/json", "{\"success\":false,\"error\":\"File not found\"}");
      }
    } else {
      server.send(200, "application/json", "{\"success\":false,\"error\":\"Invalid request format\"}");
    }
  });

  server.onNotFound(handleNotFound);          // if someone requests any other file or page, go to function 'handleNotFound'
  // and check if the file exists

#endif

  server.begin();                             // start the HTTP server
  Serial.println("[HTTP] Server started.");
}

void startWifiManager() {
  //set led pin as output
  pinMode(LED_BUILTIN, OUTPUT);
  // start ticker with long 0.6 pulses, we are in AP mode and try to connect
  ticker.attach(0.6, tick);

  //WiFiManager
  //Local intialization. Once its business is done, there is no need to keep it around
  WiFiManager wm;
  //reset settings - for testing
  //wm.resetSettings();
  //wm.setSTAStaticIPConfig(ip, gateway, subnet);

  //set callback that gets called when connecting to previous WiFi fails, and enters Access Point mode
  wm.setAPCallback(configModeCallback);

  //fetches ssid and pass and tries to connect
  //if it does not connect it starts an access point with the specified name
  //and goes into a blocking loop awaiting configuration
  if (!wm.autoConnect("airAP")) {
    Serial.println("[WIFI] Failed to connect and hit timeout");
    //reset and try again, or maybe put it to deep sleep
    ESP.restart();
    delay(1000);
  }

  //if you get here you have connected to the WiFi
  Serial.println("[WIFI] Connected :)");
  ticker.detach();
  //keep LED off
  digitalWrite(LED, HIGH);
}
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

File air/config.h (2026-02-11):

#ifndef CONFIG_H
#define CONFIG_H

#define AIR_VERSION "2.1"

//pins for wemos d1 mini
//D1: GPIO5/SCL,   D2: GPIO4/SDA,   D3: GPIO0/FLASH, D4: GPIO2, 
//D5: GPIO14/SCLK, D6: GPIO12/MISO, D7: GPIO13/MOSI, D8: GPIO15/CS

// enter into wifi configuration mode
#define RESET_MODE_PIN 2  //D4 GPIO2

//tx rx pins for software serial to communicate with AC unit
#define TX_PIN 15  //D8 GPIO15
#define RX_PIN 13  //D7 GPIO13

//i2c pins
#define I2C_SDA_PIN 4 //D2 GPIO4
#define I2C_SCL_PIN 5 //D1 GPIO5

#define MAX_LOG_DATA 72 //store up to 72 readings in a circular buffer

//#define USE_ASYNC // Use AsyncWebServer
#define USE_OTA
#define USE_SCREEN //if OLED screen installed
#define USE_MQTT // for Home Assistant integration

#define USE_AHT20     // Enable AHT20 temperature & humidity sensor
#define USE_BMP280    // Enable BMP280 temperature & pressure sensor (replaces BMP085)
#define USE_BME280    // Enable BME280 temperature, humidity & pressure sensor

//wifi credentials, no needed because now we use WiFiManager
extern const char* w_ssid;
extern const char* w_passwd;

//Over the air (OTA) credentials
extern const char* OTAName;
extern const char* OTAPassword;

// Domain name for the mDNS responder. Just connect to air.local
extern const char* mdnsName;

// Compile date and time
extern const char compile_date[];

// screen
#define SCREEN_WIDTH 128 // OLED display width, in pixels
#define SCREEN_HEIGHT 64//32 // OLED display height, in pixels
#define OLED_RESET     -1 // Reset pin # (or -1 if sharing Arduino reset pin)
#define SCREEN_ADDRESS 0x3C// See datasheet for address if you are using a different one


//#define USE_TELEGRAM

#ifdef USE_TELEGRAM
// Telegram Bot configuration - Replace with your values
extern const char* telegram_bot_token;
extern const char* telegram_chat_id;
#endif


#endif //CONFIG_H

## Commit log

2020-08-05 save mode, colored buttons, fixed ip, temp and more fixes
    [air.ino]
2020-08-20 fix parsingm, preliminary chartjs
    [air.ino]
2020-09-05 fix temp, heat. fix date on graph
    [air.ino]
2020-10-03 pcb and logs
    [airpcb.dsn, airpcb.kicad_pcb, airpcb.sch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]
2020-11-06 fix bmp and parser alternative
    [air.ino]
2021-01-03 Update README.md
    pre-heat code
2021-06-22 fix some crashes and graph
    [air.ino]
2022-01-05 reduce log size, may cause problems
    [air.ino, config.h]
2022-02-11 websocket.loop fixed. thnx cmc88
    [air.ino]
2025-07-25 home assintant discovery fixed, sensors, temp chart and more
    [ac_protocol.cpp, ac_protocol.h, air.ino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]
2025-08-09 fix timer, improved ws responsiveness, simulation mode
    [ac_protocol.cpp, ac_protocol.h, air.ino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]
2025-08-12 fix timeseries, refactor sensor reading
    [air.ino, process_request.cpp]
2026-02-11 Update temperature coding and remote temp reporting details
    Clarify temperature coding and remote temperature reporting format in README.
